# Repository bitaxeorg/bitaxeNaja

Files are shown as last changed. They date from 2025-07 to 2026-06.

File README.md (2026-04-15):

BitaxeNaja is a dual BM1340 Open Source Bitcoin miner using [esp-miner](https://github.com/skot/esp-miner)

The BM1340 used in this design is suspected to be a prototype version of the ASIC used in the Antminer S23 series miners.

It is still an untested prototype! Don't build this expecting it to work at all.
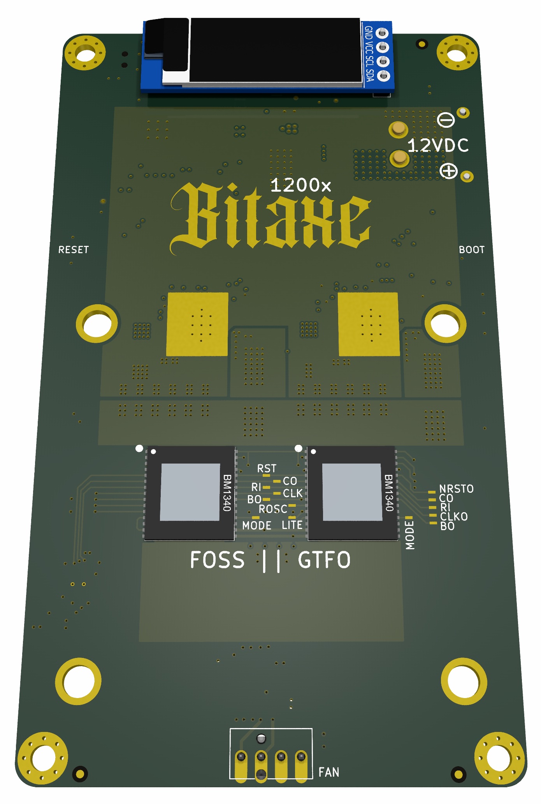
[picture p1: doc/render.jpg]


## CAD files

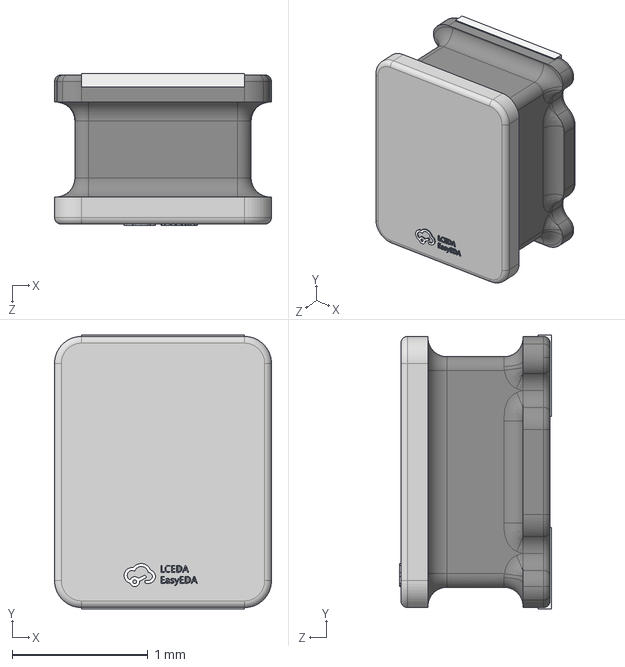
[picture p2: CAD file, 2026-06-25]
3d/IND-SMD_L2.0-W1.6-H1.1.step
1.60 x 2.02 x 1.12 mm

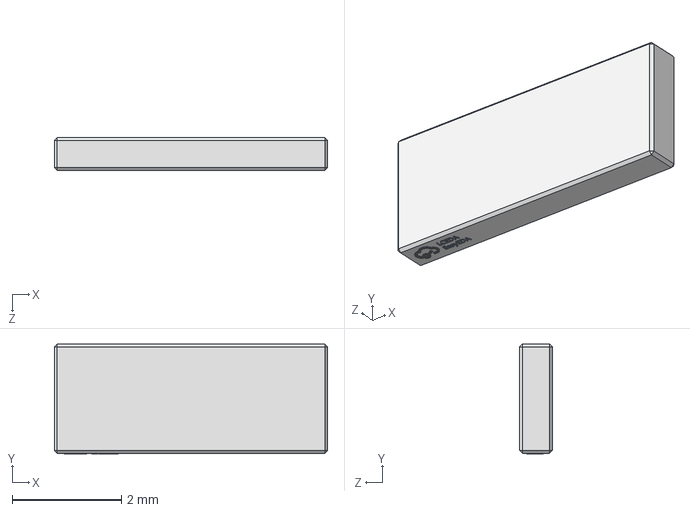
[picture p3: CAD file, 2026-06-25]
3d/PAD-SMD_L5.0-W2.0_STHW4-DU-HN050206.step
5.00 x 2.01 x 0.6 mm

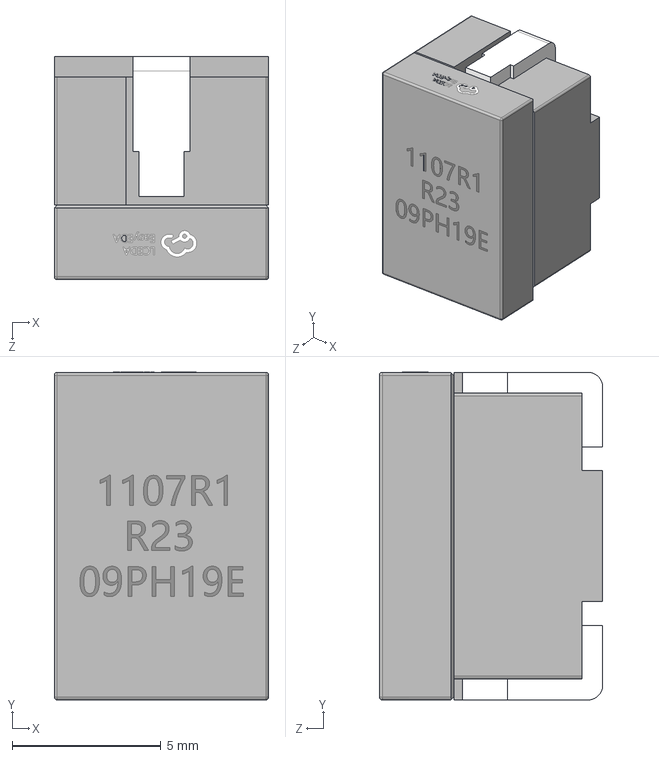
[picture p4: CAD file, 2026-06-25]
3d/IND-SMD_L11.0-W7.2-H7.5.step
7.20 x 11.0 x 7.50 mm

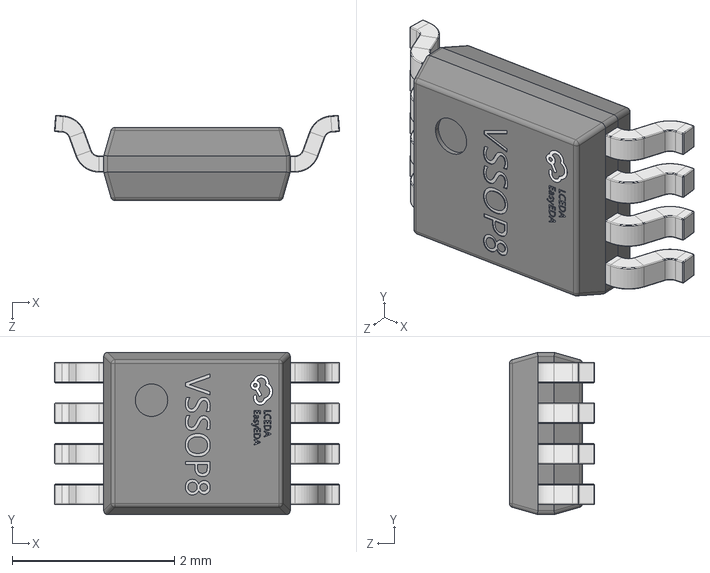
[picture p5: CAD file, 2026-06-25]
3d/VSSOP-8_L2.0-W2.3-H0.9-LS3.1-P0.50.step
3.51 x 2.00 x 1.05 mm

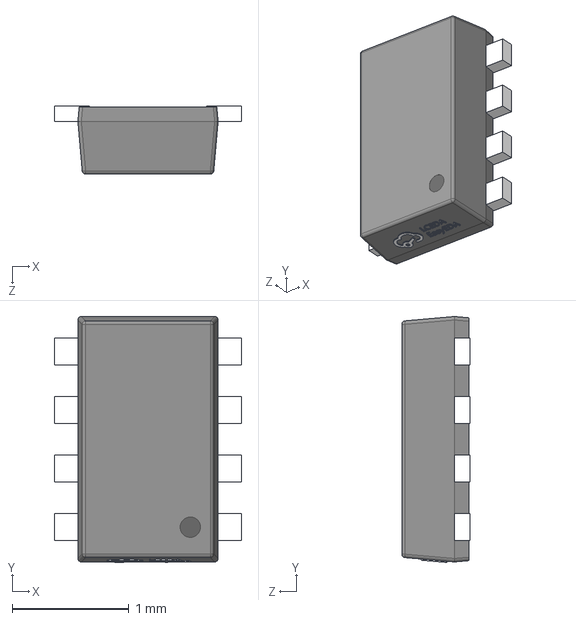
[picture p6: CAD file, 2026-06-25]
3d/SOT-583-8_L2.1-W1.2-P0.50-LS1.6-BR.step
1.60 x 2.10 x 0.585 mm

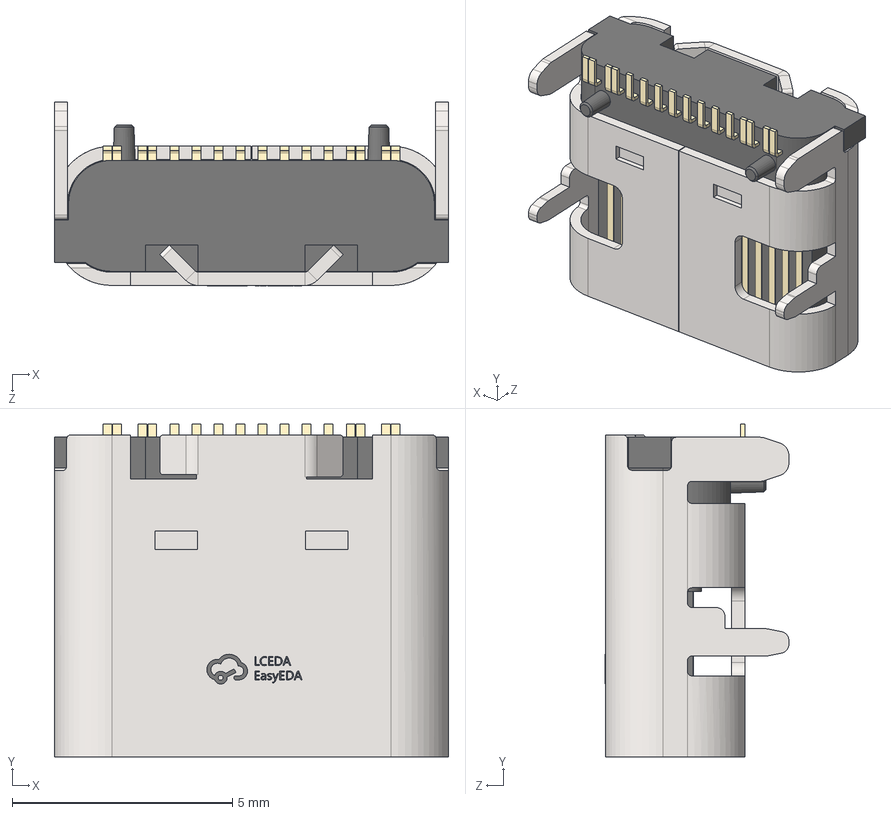
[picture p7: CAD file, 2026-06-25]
3d/TYPE-C-SMD_SBC-160S1A-20-S412.step
8.94 x 7.55 x 4.17 mm

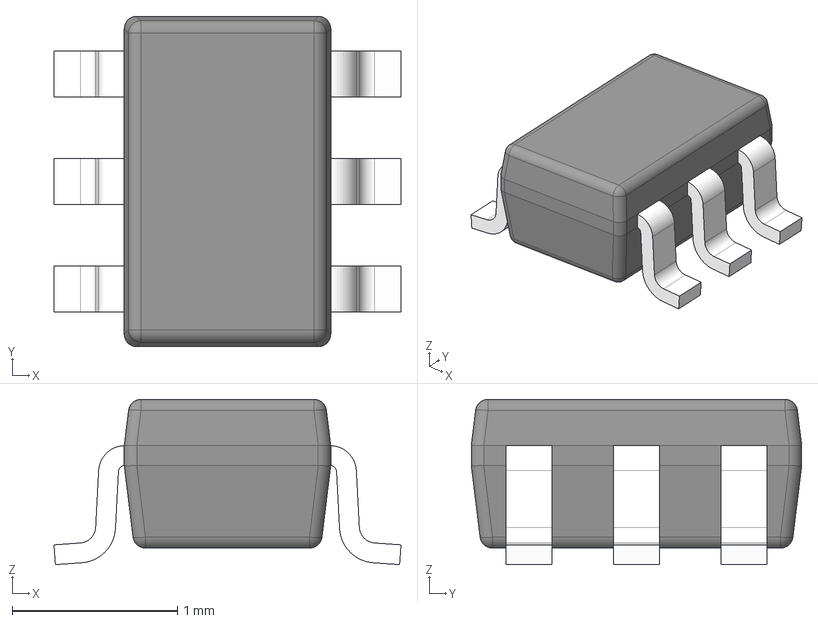
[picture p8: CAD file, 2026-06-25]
3d/DCK0006A.stp
2.10 x 2.00 x 1.00 mm
BODY-SOT
LEAD-SOT x 6
PIN1-ID

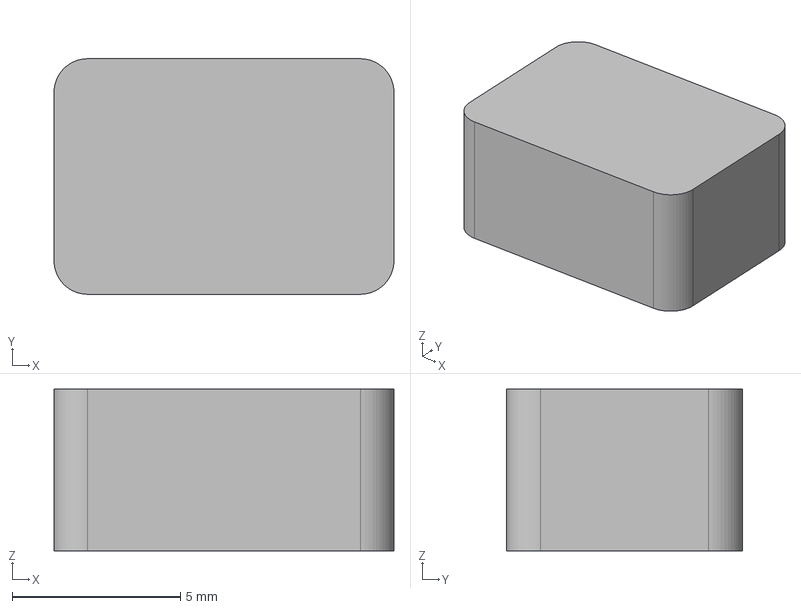
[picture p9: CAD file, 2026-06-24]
3d/GDIM107050-R15S1MTF-0R37.step
10.1 x 7.00 x 4.80 mm

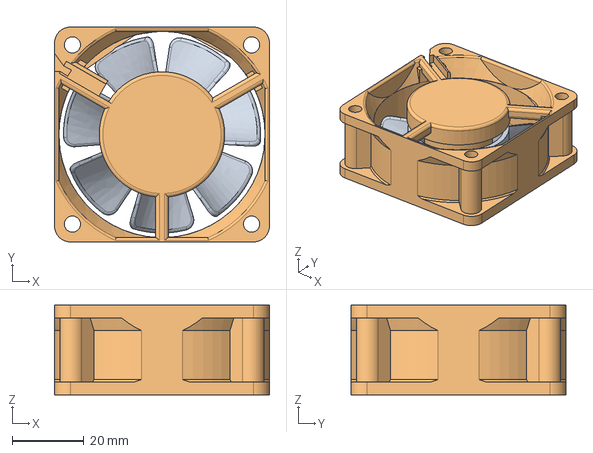
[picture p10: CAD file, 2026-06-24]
3d/Fan 60x60x25mm.stp
60.0 x 60.0 x 25.0 mm

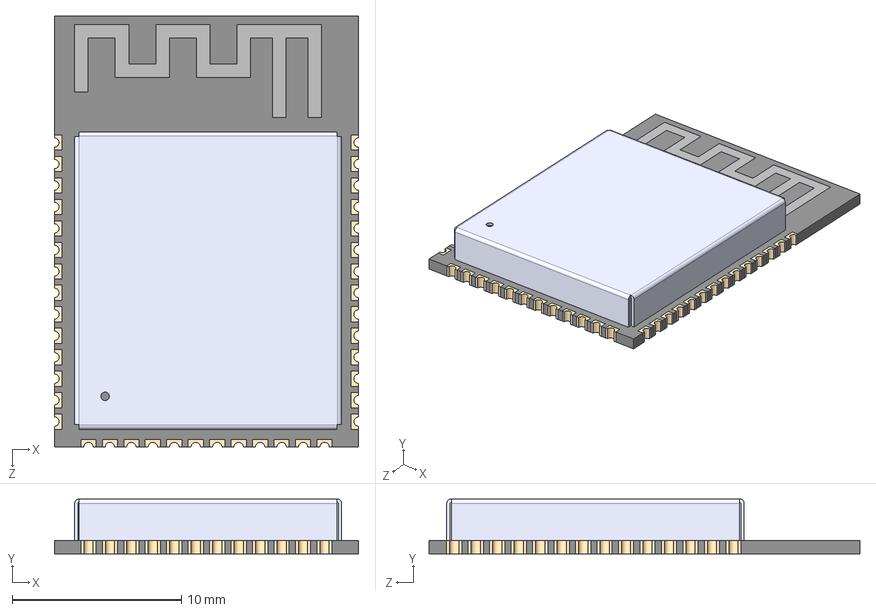
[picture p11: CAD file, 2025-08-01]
3d/ESP32-S3-WROOM-1-N8R2--3DModel-STEP-56544.STEP
18.0 x 3.25 x 25.5 mm

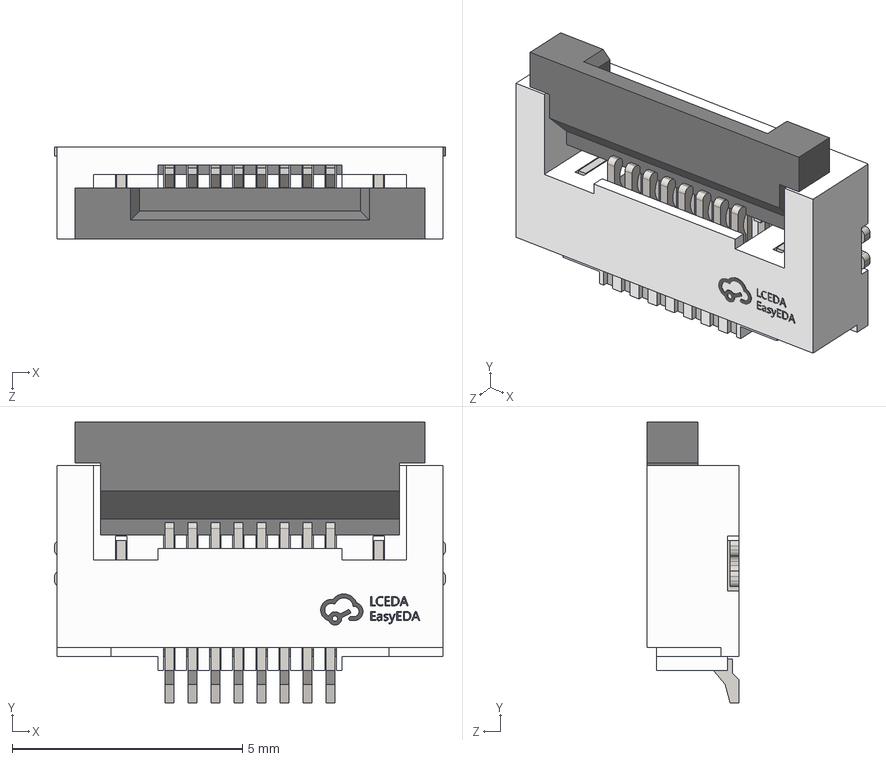
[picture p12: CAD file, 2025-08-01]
3d/FPC-SMD_P0.50-8P_FGS-XJ-H2.0.step
8.50 x 6.10 x 2.01 mm

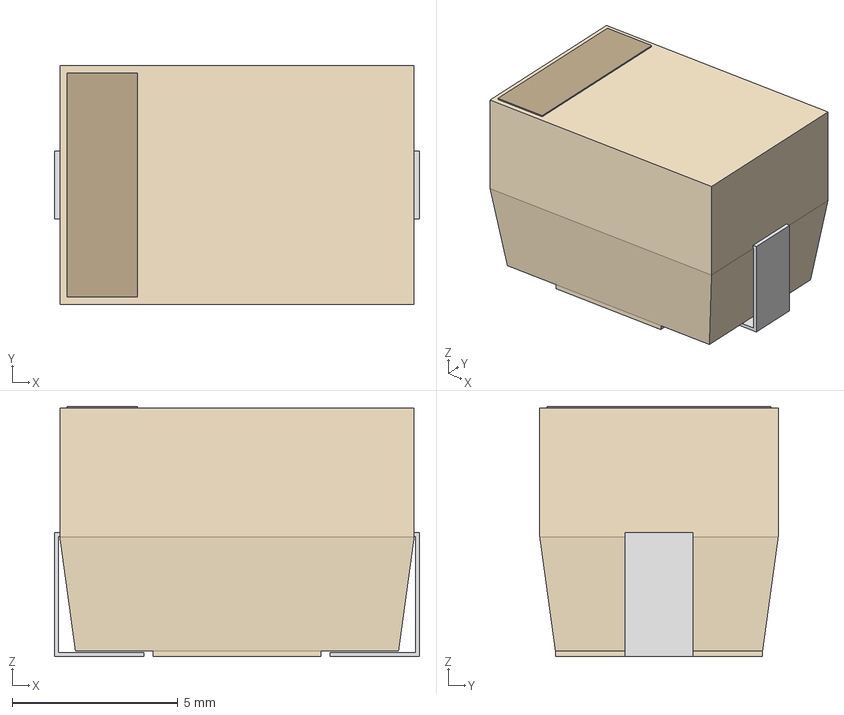
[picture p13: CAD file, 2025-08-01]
3d/IND_FP1107R1_EAT.step
11.0 x 7.19 x 7.54 mm

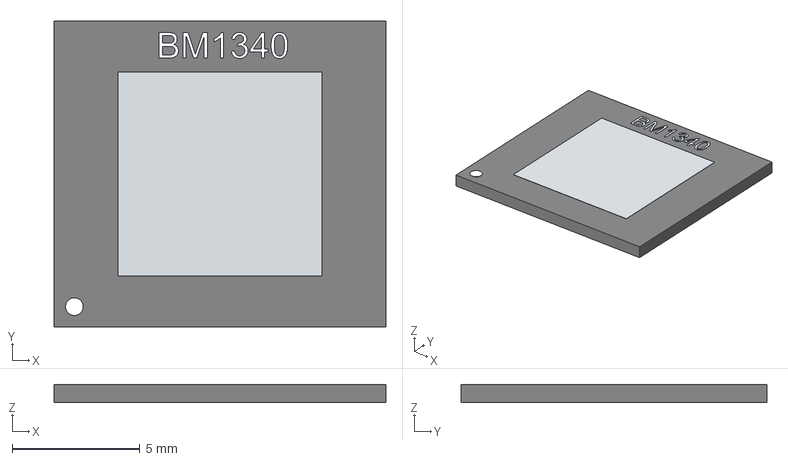
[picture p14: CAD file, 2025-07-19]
3d/BM1340.step
13.0 x 12.0 x 0.71 mm
Sketch002
Sketch003

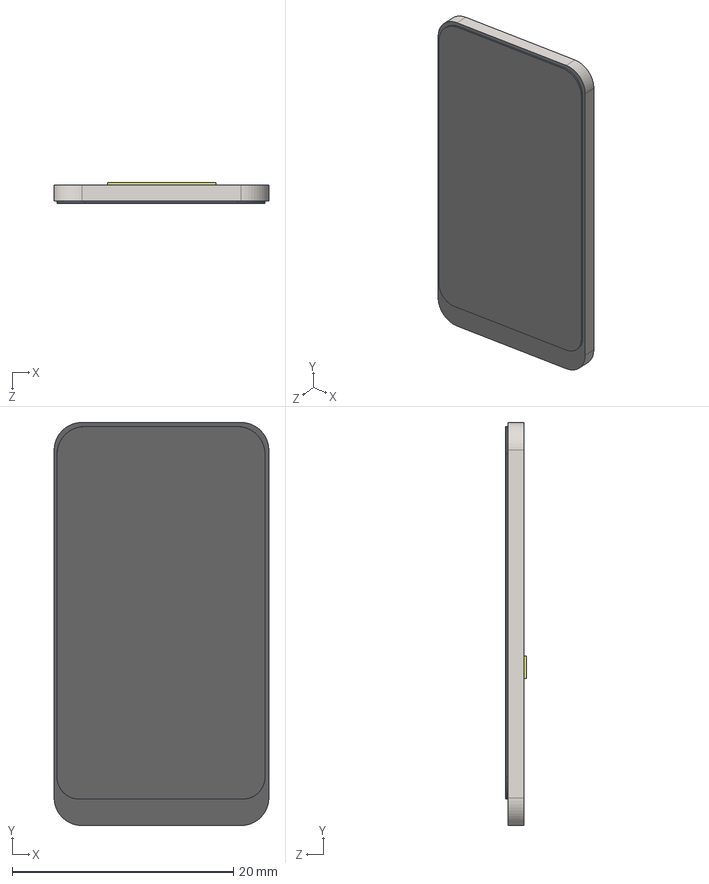
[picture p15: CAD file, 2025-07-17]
3d/DISST7789-176x320.STEP
19.4 x 36.4 x 1.86 mm

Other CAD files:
3d/TXB0104RGYR.STEP
3d/TPS546D24ARVFR.step
3d/BitaxeGT_heatsink.step
3d/BM04B-SRSS-TB.STEP
3d/141_TL3330AFxxxQG.stp
3d/21-0164B_L622-1_MXM.step
3d/2R5TPE220MAFB.step
3d/470531000.stp
3d/54-00164.STEP
3d/BM1368xx.stp
3d/BQB0016A.stp
3d/Bitaxe_Heatsink.step
3d/CS1213AG-tr.stp
3d/CUI_DEVICES_PJ-002AH.step
3d/CUI_DEVICES_PJ-036AH-SMT-TR.step
3d/CUI_DEVICES_PJ-037AH.step
3d/CX3225SB16000H0FLJCC.STEP
3d/Coilcraft-SLC1175.STEP
3d/Cree_PLCC6.stp
3d/DHVQFN14_SOT762-1_NEX.step
3d/DQG0008A.stp
3d/DQH0008A.stp
3d/DRC0010J.stp
3d/DRL0006A.stp
3d/FFC2B35-08-T.STEP
3d/FP1006V2-R.STEP
3d/FTSH-105-01-F-DV-K.stp
3d/GT heatsink.step
3d/IHLP2020CZ.step
3d/IND_-1R5MC_SUM.step
3d/OLED_0.91_128x32.stp
3d/PLCC6_LED_3_5X3_4X2_8_CRW.step
3d/QFN16_4X4_MCH.step
3d/SLC1175-271MEC_COC.step
3d/SMV_z90.stp
3d/SN74AXC1T45DBVR.STEP
3d/SOT-23-5_M5_MCH.step
3d/ST-4ETB2k_(202).stp
3d/SW_CS1213AGF260_CRS.step
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

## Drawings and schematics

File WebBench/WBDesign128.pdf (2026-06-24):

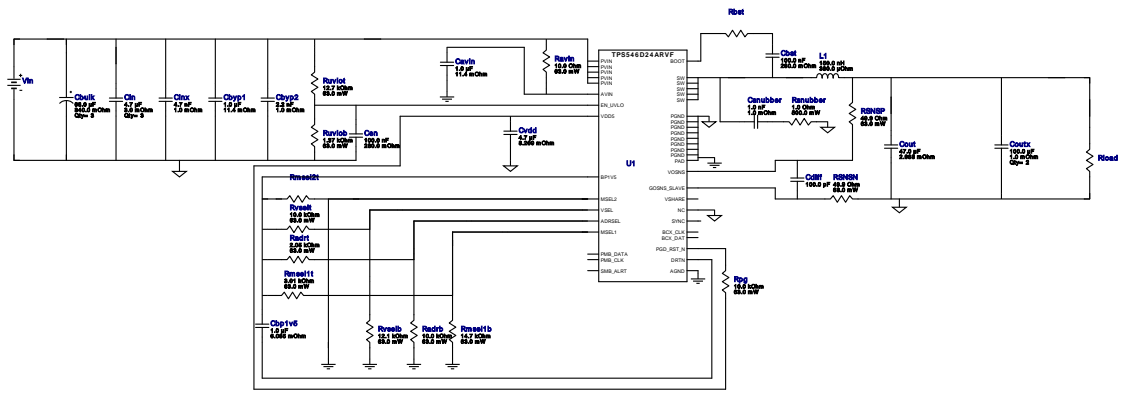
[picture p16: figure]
Cbyp2 2.2 nF 1.0 m Ohm; Cen 100.0 nF 280.0 m Ohm; Rsnubber 1.0 Ohm; Ruvlob 1.37 kOhm 63.0 m W; Cdiff 100.0 pF; Cavin 1.0 µF 11.4 m Ohm Ruvlot 12.7 kOhm; Coutx 100.0 µF 1.0 m Ohm Qty= 2; Cin 4.7 µF 3.0 m Ohm Qty= 3; RSNSN 49.9 Ohm 63.0 m W; Cout 47.0 µF; 2.988 m Ohm; RSNSP 49.9 Ohm 63.0 m W; Cinx 4.7 nF 1.0 m Ohm; Cbp1v5 1.0 µF 6.065 m Ohm; Cbyp1 1.0 µF 11.4 m Ohm; Rvselb 12.1 kOhm 63.0 m W; Rbst; Rpg 10.0 kOhm 63.0 m W; Ravin 10.0 Ohm 63.0 m W; Radrt 2.05 kOhm; Rm sel2t; Rvselt 10.0 kOhm; L1 150.0 nH 390.0 µOhm; Csnubber 1.0 nF; 1.0 m Ohm; Cbulk 68.0 µF 340.0 m Ohm; Qty= 3; Cvdd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

Copyright © 2026, Texas Instruments Incorporated | 1 | ti.com/webench

WEBENCH®
Design Report TPS546D24ARVFR : TPS546D24ARVFR 11V-13V to 2.20V @ 30A June 18, 2026 14:52:07 GMT-05:00

## WEBENCH ® Design Report

Design : 128 TPS546D24ARVFR
TPS546D24ARVFR 11V-13V to 2.20V @ 30A

VinMin = 11.0V
VinMax = 13.0V
Vout = 2.2V
Vout Sch = 2.2V
Iout = 30.0A

Device = TPS546D24ARVFR
Topology = Buck
Created = 2025-09-15 13:40:46.376 BOM Cost = $7.43
BOM Count = 34
Total Pd = 6.61W
1. Do not place Rmsel2t resistors. Place 0 Ohm resistor for Rbst.

### Design Alerts

Component Selection Information
The TPS546D24A is a PMBus(TM) device with key features listed below: PMBus(TM) features marked with * are included in WEBENCH(R) Power Designer. - Adaptive Voltage Scaling (AVS) through VOUT_COMMAND*, - Output voltage and current monitoring, - Thermal Shutdown,
- Programmable over current protection, - OCP,OV, UV, OT Levels, - Selectable Internal Compensation*, - Selectable Switching Frequency*,
- Turn-On and Turn-Off Delays, - UVLO*, Soft-Start*,OCP* and Soft-Stop. Use the Advanced Options on the left side to set the PMBus(TM) commands. Please refer to the TPS546D24A datasheet and visit http://www.ti.com/pmbus for more information.

## Electrical BOM

Name | Manufacturer | Part Number | Properties | Qty Price | Footprint
Cavin | TDK | C1005X5R1E105K050BC (https://product.tdk.com/ja/search/capacitor/ceramic/mlcc/info?part%5Fno%3DC1005X5R1E105K050BC) Series= X5R | Cap= 1.0 uF ESR= 11.4 mOhm VDC= 25.0 V IRMS= 0.0 A
1 | $0.02
| | | | | 0402 3 mm²
Cbp1v5 | MuRata | GRM188R60J105KA01D (http://psearch.en.murata.com/capacitor/result/smd/?status%3Dall%26pid%3DGRM188R60J105KA01D) Series= X5R

Cap= 1.0 uF
ESR= 6.065 mOhm
VDC= 6.3 V
IRMS= 1.36934 A

1 $0.01
0603 5 mm²
Cbst | AVX | 08053C104KAT2A (http://datasheets.avx.com/X7RDielectric.pdf) Series= X7R

Cap= 100.0 nF
ESR= 280.0 mOhm
VDC= 25.0 V
IRMS= 0.0 A

1 $0.01
0805 7 mm²

Design

Copyright © 2026, Texas Instruments Incorporated | 2 | ti.com/webench
Name | Manufacturer | Part Number | Properties | Qty Price | Footprint
Cbulk | Nichicon | UUD1V680MCL1GS (http://products.nichicon.co.jp/en/pdf/XJA043/e%2Dud.pdf) Series= uD | Cap= 68.0 uF ESR= 340.0 mOhm VDC= 35.0 V IRMS= 280.0 mA
3 | $0.10
| | | | | SM_RADIAL_6.3BMM 80 mm²
Cbyp1 | TDK | C1005X5R1E105K050BC (https://product.tdk.com/ja/search/capacitor/ceramic/mlcc/info?part%5Fno%3DC1005X5R1E105K050BC) Series= X5R | Cap= 1.0 uF ESR= 11.4 mOhm VDC= 25.0 V IRMS= 0.0 A
1 | $0.02
| | | | | 0402 3 mm²
Cbyp2 | MuRata | GRM155R61E222KA01D (http://search.murata.co.jp/Ceramy/PnsearchViewAction.do) Series= X5R

Cap= 2.2 nF
ESR= 1.0 mOhm
VDC= 25.0 V
IRMS= 0.0 A

1 $0.01
0402 3 mm²
Cdiff | Yageo | CC0201JRNPO8BN101 (http://www.yageo.com/documents/recent/UPY%2DGP%5FNP0%5F16V%2Dto%2D50V%5F10.pdf) Series= C0G/NP0

Cap= 100.0 pF
VDC= 5.0 V
IRMS= 0.0 A

1 $0.01
0201 2 mm²
Cen | AVX | 08053C104KAT2A (http://datasheets.avx.com/X7RDielectric.pdf) Series= X7R

Cap= 100.0 nF
ESR= 280.0 mOhm
VDC= 25.0 V
IRMS= 0.0 A

1 $0.01
0805 7 mm²
Cin | MuRata | GRM31CR71H475KA12L (http://search.murata.co.jp/Ceramy/PnsearchViewAction.do) Series= X7R

Cap= 4.7 uF
ESR= 3.0 mOhm
VDC= 50.0 V
IRMS= 4.98 A

3 $0.10
1206 11 mm²
Cinx | MuRata | GRM155R71E472KA01D (http://search.murata.co.jp/Ceramy/PnsearchViewAction.do) Series= X7R

Cap= 4.7 nF
ESR= 1.0 mOhm
VDC= 25.0 V
IRMS= 0.0 A

1 $0.01
0402 3 mm²
Cout | Taiyo Yuden | MSASJ21GBB5476MTNA01 (https://ds.yuden.co.jp/TYCOMPAS/ut/detail?pn%3DMSASJ21GBB5476MTNA01%26u%3DM) Series= X5R

Cap= 47.0 uF
ESR= 2.988 mOhm
VDC= 6.3 V
IRMS= 3.5841 A

1 $0.09
0805 7 mm²
Coutx | MuRata | GRM32EC80J107ME20L Series= X6S

Cap= 100.0 uF
ESR= 1.0 mOhm
VDC= 6.3 V
IRMS= 6.0 A

2 $0.17
1210_270 15 mm²
Csnubber Yageo | CC0805KRX7R9BB102 (http://www.yageo.com/documents/recent/UPY%2DGPHC%5FX7R%5F6.3V%2Dto%2D50V%5F7.pdf)
| | Series= X7R
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

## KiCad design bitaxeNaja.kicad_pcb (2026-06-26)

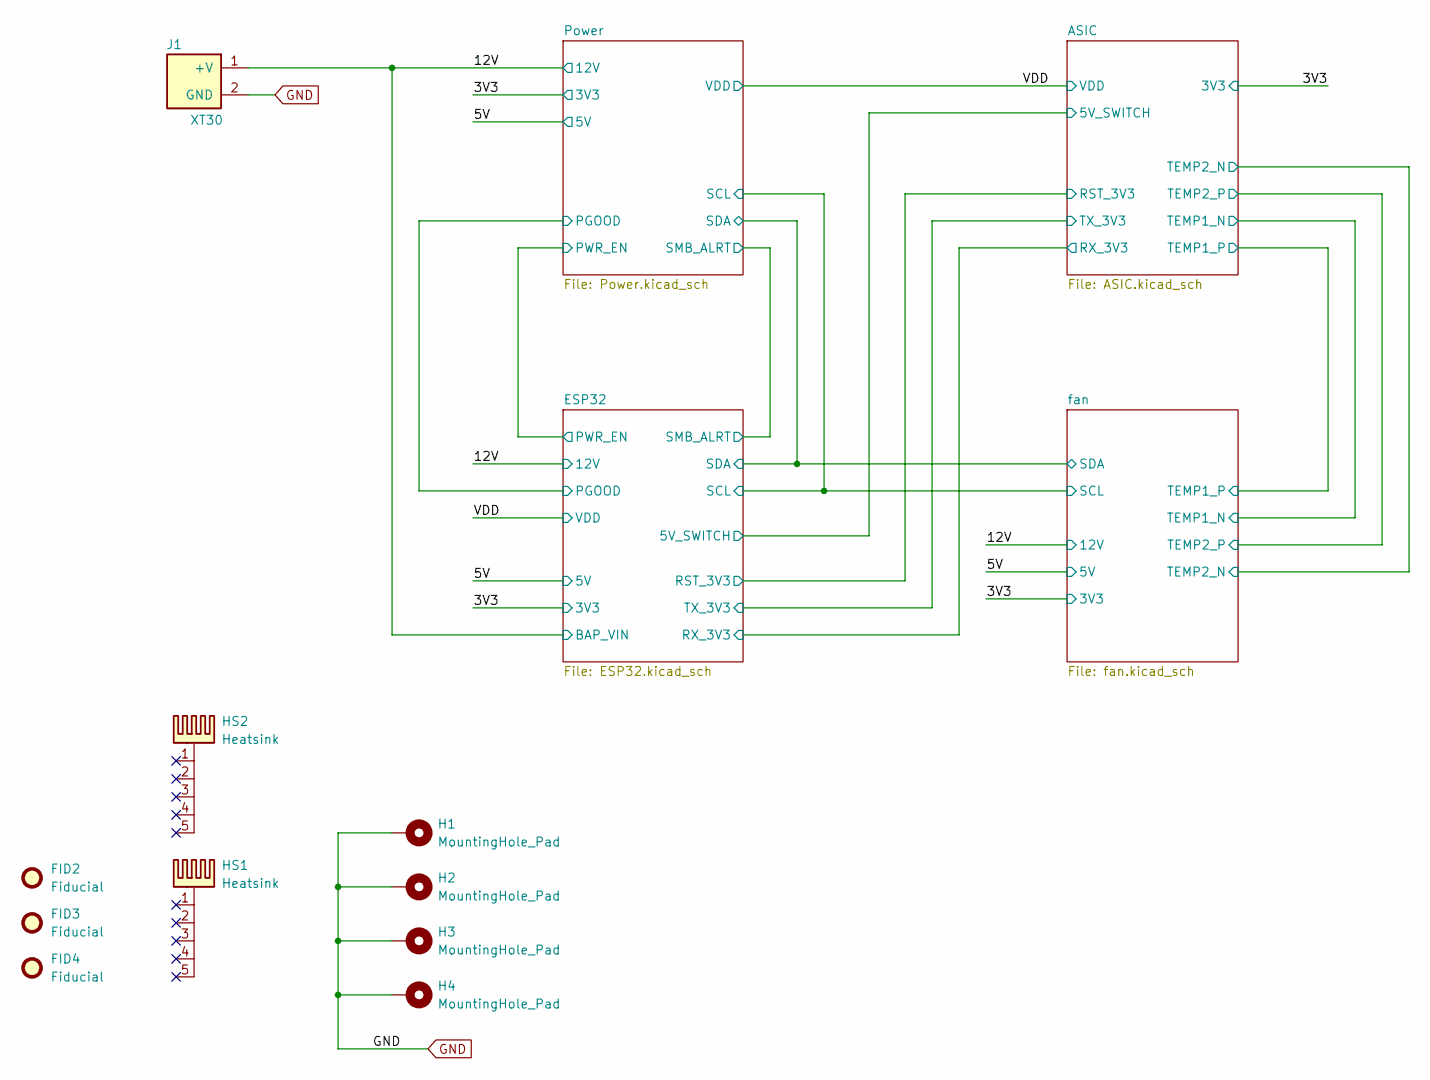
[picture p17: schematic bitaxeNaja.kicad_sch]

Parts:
FID2, FID3, FID4: Fiducial; Fiducial_1mm_Mask2mm
H1, H2, H3, H4: MountingHole_Pad; MountingHole_3.2mm_M3_Pad_Via
HS1: Heatsink; Heatsink-5hole-BitaxeGT
HS2: Heatsink; 70mm-mounting_HTPC
J1: XT30; XT30PW-M; PARTNO XT30PW-M; LCSC C431092

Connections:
/12V: J1.1 (+V); also elsewhere on the board
GND: H1.1 (1_1), H2.1 (1_1), H3.1 (1_1), H4.1 (1_1), J1.2 (GND); also elsewhere on the board

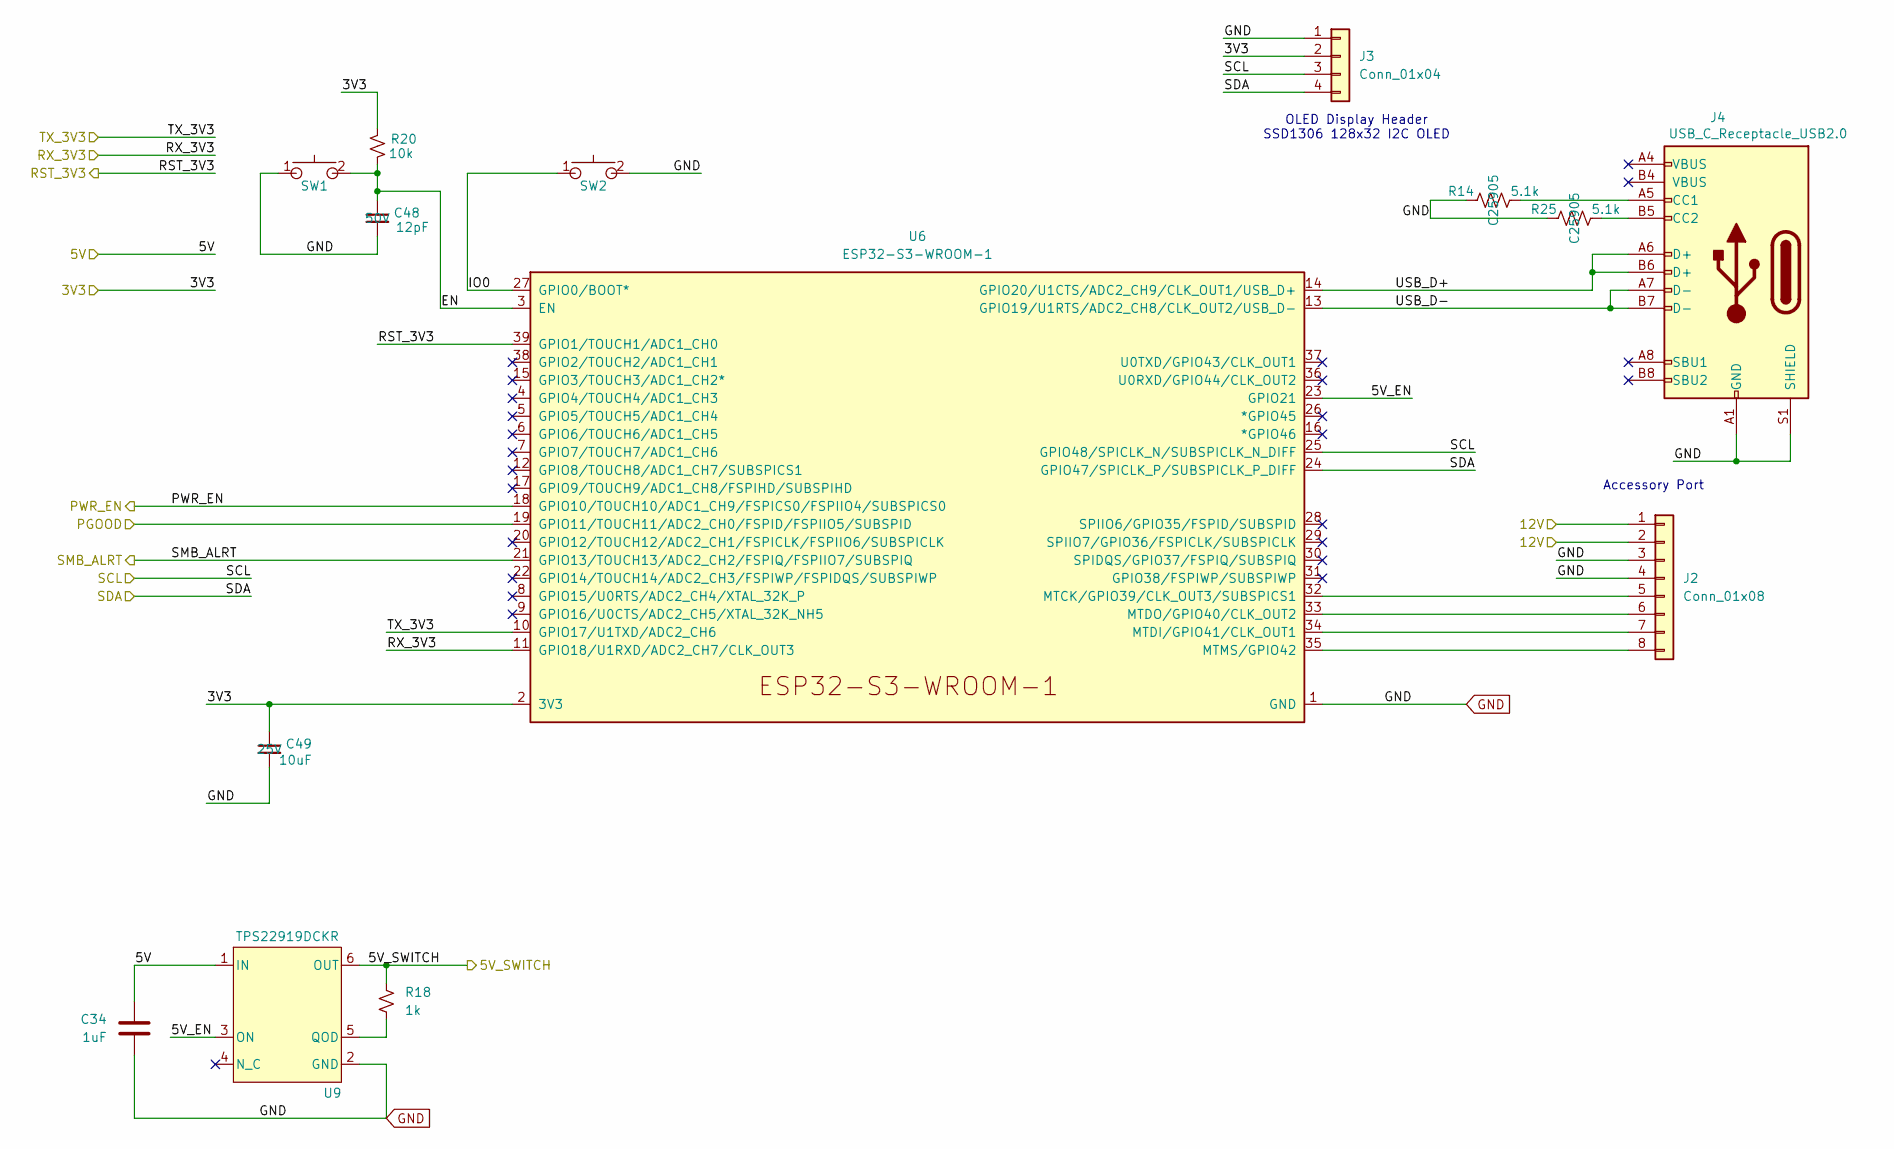
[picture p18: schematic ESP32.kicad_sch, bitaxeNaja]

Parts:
C34: 1uF; C_0402_1005Metric; PARTNO EMK105BJ105MV-F; LCSC C52923
C48: 12pF; C_0402_1005Metric; Voltage 50V; PARTNO CC0402JRNPO9BN120
C49: 10uF; C_0603_1608Metric; Voltage 25V; PARTNO GRM188R61E106KA73D
J2: Conn_01x08; FPC-SMD_P0.50-8P_FGS-XJ-H2.0; PARTNO FFC2B35-08-T; LCSC C262657
J3: Conn_01x04; PinHeader_1x04_P2.54mm_Vertical_shifted
J4: USB_C_Receptacle_USB2.0; USB_C_Receptacle_GCT_USB4105-xx-A; PARTNO USB4105-GF-A
R14, R25: 5.1k; R_0402_1005Metric; PARTNO RMCF0402JT5K10; LCSC C25905
R18: 1k; R_0402_1005Metric; PARTNO RC0402FR-071KL
R20: 10k; R_0402_1005Metric; PARTNO RC0402JR-0710KL
SW1, SW2: SWITCH-SPST; SW_TL3330AF130QG_EWI; PARTNO TL3330AF130QG
U6: ESP32-S3-WROOM-1; PARTNO ESP32-S3-WROOM-1-N16R8
U9: TPS22919DCKR; DCK0006A_N; PARTNO TPS22919DCKR

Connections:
/3V3: C49.1, J3.2, R20.2, U6.2 (3V3); also elsewhere on the board
/5V: C34.1, U9.1 (IN); also elsewhere on the board
/12V: J2.1, J2.2; also elsewhere on the board
/ASIC/5V_SWITCH: R18.1, U9.6 (OUT); also elsewhere on the board
/ASIC/RST_3V3: U6.39 (GPIO1/TOUCH1/ADC1_CH0); also elsewhere on the board
/ASIC/RX_3V3: U6.11 (GPIO18/U1RXD/ADC2_CH7/CLK_OUT3); also elsewhere on the board
/ASIC/TX_3V3: U6.10 (GPIO17/U1TXD/ADC2_CH6); also elsewhere on the board
/ESP32/5V_EN: U6.23 (GPIO21), U9.3 (ON)
/ESP32/EN: C48.1, R20.1, SW1.2, U6.3 (EN)
/ESP32/IO0: SW2.1, U6.27 (GPIO0/BOOT*)
/ESP32/PWR_EN: U6.18 (GPIO10/TOUCH10/ADC1_CH9/FSPICS0/FSPIIO4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); also elsewhere on the board
/ESP32/SCL: J3.3, U6.25 (GPIO48/SPICLK_N/SUBSPICLK_N_DIFF); also elsewhere on the board
/ESP32/SDA: J3.4, U6.24 (GPIO47/SPICLK_P/SUBSPICLK_P_DIFF); also elsewhere on the board
/ESP32/SMB_ALRT: U6.21 (GPIO13/TOUCH13/ADC2_CH2/FSPIQ/FSPIIO7/S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); also elsewhere on the board
/ESP32/USB_D+: J4.A6 (D+), J4.B6 (D+), U6.14 (GPIO20/U1CTS/ADC2_CH9/CLK_OUT1/USB_D+)
/ESP32/USB_D-: J4.A7 (D-), J4.B7 (D-), U6.13 (GPIO19/U1RTS/ADC2_CH8/CLK_OUT2/USB_D-)
/Power/PGOOD: U6.19 (GPIO11/TOUCH11/ADC2_CH0/FSPID/FSPIIO5/S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); also elsewhere on the board
GND: C34.2, C48.2, C49.2, J2.3, J2.4, J3.1, J4.A1 (GND), J4.B1 (GND), J4.S1 (SHIELD), R14.1, R25.1, SW1.1, SW2.2, U6.1 (GND), U6.40 (GND), U6.41 (GND), U9.2 (GND); also elsewhere on the board
unnamed: J2.5, U6.32 (MTCK/GPIO39/CLK_OUT3/SUBSPICS1)
unnamed: J2.6, U6.33 (MTDO/GPIO40/CLK_OUT2)
unnamed: J2.7, U6.34 (MTDI/GPIO41/CLK_OUT1)
unnamed: J2.8, U6.35 (MTMS/GPIO42)
unnamed: J4.A5 (CC1), R14.2
unnamed: J4.B5 (CC2), R25.2
unnamed: R18.2, U9.5 (QOD)

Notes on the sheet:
OLED Display Header SSD1306 128x32 I2C OLED
Accessory Port

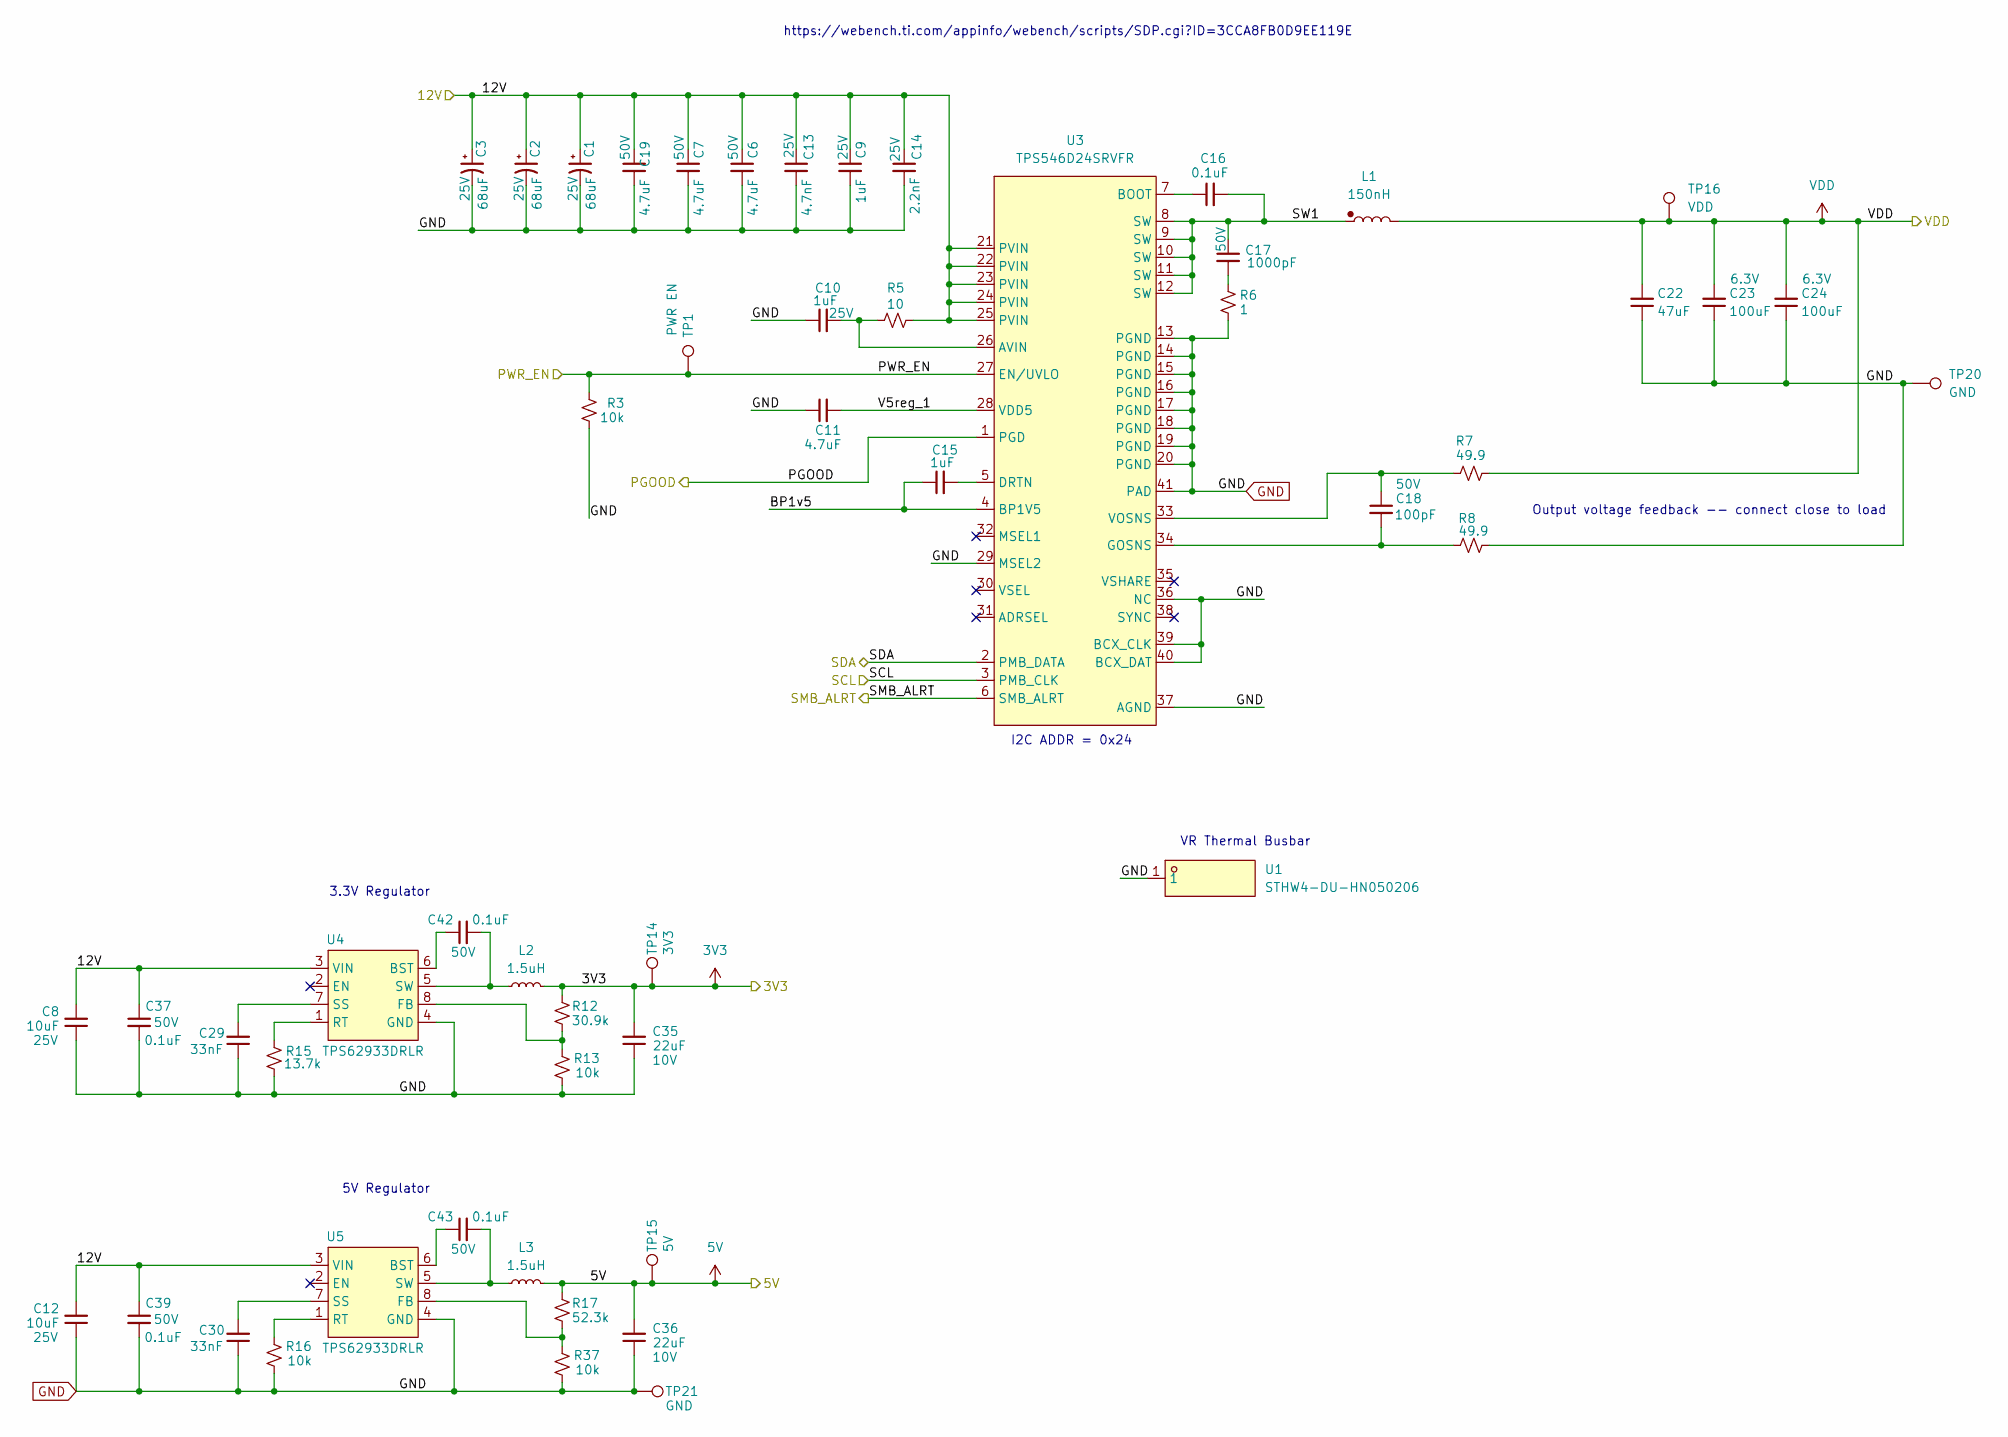
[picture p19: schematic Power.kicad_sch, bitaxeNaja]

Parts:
C1, C2, C3: 68uF; CP_Elec_5x5.8; Voltage 25V; PARTNO UCM1E680MCL1GS
C6, C7, C19: 4.7uF; C_1206_3216Metric; Voltage 50V; PARTNO GRM31CR71H475KA12L
C8, C12: 10uF; C_0603_1608Metric; Voltage 25V; PARTNO GRM188R61E106KA73D; LCSC C15850
C9, C10: 1uF; C_0603_1608Metric; Voltage 25V; PARTNO CL10B105KA8NNNC
C11: 4.7uF; C_0402_1005Metric; PARTNO GRM155R61A475MEAAD
C13: 4.7nF; C_0402_1005Metric; Voltage 25V; PARTNO GRM155R71E472KA01D
C14: 2.2nF; C_0402_1005Metric; Voltage 25V; PARTNO GRM155R61H222KA01D
C15: 1uF; C_0402_1005Metric; PARTNO EMK105BJ105MV-F; LCSC C52923
C16, C37, C39, C42, C43: 0.1uF; C_0402_1005Metric; Voltage 50V; PARTNO GRM155R71H104KE14D; LCSC C77020
C17: 1000pF; C_0805_2012Metric; Voltage 50V; PARTNO CC0805KRX7R9BB102
C18: 100pF; C_0402_1005Metric; Voltage 50V; PARTNO CC0402JRNPO9BN101
C22: 47uF; C_0805_2012Metric; PARTNO MSASJ21GBB5476MTNA01; LCSC C45783
C23, C24: 100uF; C_1210_3225Metric; Voltage 6.3V; PARTNO GRM32EC80J107ME20L
C29, C30: 33nF; C_0402_1005Metric; PARTNO CC0402KRX7R9BB333; LCSC C106862
C35, C36: 22uF; C_0805_2012Metric; Voltage 10V; PARTNO CL21A226MPQNNNE; LCSC C45783
L1: 150nH; GDIM107050-R15S1MTF-0R37; LCSC C49237960
L2, L3: 1.5uH; IND-SMD_L2.0-W1.6; PARTNO FTC201612S1R5MBCA; LCSC C5832350
R3, R13, R16, R37: 10k; R_0402_1005Metric; PARTNO RC0402JR-0710KL; LCSC C25744
R5: 10; R_0402_1005Metric; PARTNO RC0402FR-0710RL
R6: 1; R_0805_2012Metric; PARTNO ESR10EZPJ1R0
R7, R8: 49.9; R_0402_1005Metric; PARTNO RC0402FR-0749R9L
R12: 30.9k; R_0402_1005Metric; PARTNO RC0402FR-0730K9L; LCSC C185428
R15: 13.7k; R_0402_1005Metric; PARTNO RC0402FR-0713K7L; LCSC C274888
R17: 52.3k; R_0402_1005Metric; PARTNO RC0402FR-0752K3L
TP1: PWR EN; TestPoint_Pad_D1.0mm
TP14: 3V3; TestPoint_Pad_D1.0mm
TP15: 5V; TestPoint_Pad_D1.0mm
TP16: VDD; TestPoint_Pad_D1.0mm
TP20: GND; TestPoint_Pad_D1.0mm
TP21: GND; TestPoint_Pad_D1.0mm; LCSC C138021
U1: STHW4-DU-HN050206; PAD-SMD_L5.0-W2.0_STHW4-DU-HN050206; LCSC C18548300
U3: TPS546D24SRVFR; LQFN40-CLIP; PARTNO TPS546D24SRVFR
U4, U5: TPS62933DRLR; SOT-583-8_L2.1-W1.2-P0.50-LS1.6-BR; PARTNO TPS62933DRLR; LCSC C3200405

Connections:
/3V3: C35.2, L2.2, R12.2, TP14.1 (1_1); also elsewhere on the board
/5V: C36.2, L3.2, R17.2, TP15.1 (1_1); also elsewhere on the board
/12V: C1.1, C2.1, C3.1, C6.1, C7.1, C8.2, C9.1, C12.2, C13.1, C14.1, C19.1, C37.1, C39.1, R5.1, U3.21 (PVIN), U3.22 (PVIN), U3.23 (PVIN), U3.24 (PVIN), U3.25 (PVIN), U4.3 (VIN), U5.3 (VIN); also elsewhere on the board
/ESP32/PWR_EN: R3.2, TP1.1 (1_1), U3.27 (EN/UVLO); also elsewhere on the board
/ESP32/SCL: U3.3 (PMB_CLK); also elsewhere on the board
/ESP32/SDA: U3.2 (PMB_DATA); also elsewhere on the board
/ESP32/SMB_ALRT: U3.6 (SMB_ALRT); also elsewhere on the board
/Power/BP1v5: C15.1, U3.4 (BP1V5)
/Power/PGOOD: U3.1 (PGD); also elsewhere on the board
/Power/SW1: C16.2, C17.1, L1.1, U3.8 (SW), U3.9 (SW), U3.10 (SW), U3.11 (SW), U3.12 (SW)
/Power/V5reg_1: C11.2, U3.28 (VDD5)
/VDD: C22.2, C23.2, C24.2, L1.2, R7.1, TP16.1 (1_1); also elsewhere on the board
GND: C1.2, C2.2, C3.2, C6.2, C7.2, C8.1, C9.2, C10.1, C11.1, C12.1, C13.2, C14.2, C19.2, C22.1, C23.1, C24.1, C29.1, C30.1, C35.1, C36.1, C37.2, C39.2, R3.1, R6.2, R8.2, R13.1, R15.1, R16.1, R37.1, TP20.1 (1_1), TP21.1 (1_1), U1.1 (1_1), U3.13 (PGND), U3.14 (PGND), U3.15 (PGND), U3.16 (PGND), U3.17 (PGND), U3.18 (PGND), U3.19 (PGND), U3.20 (PGND), U3.29 (MSEL2), U3.36 (NC), U3.37 (AGND), U3.39 (BCX_CLK), U3.40 (BCX_DAT), U3.41 (PAD), U4.4 (GND), U5.4 (GND); also elsewhere on the board
unnamed: C17.2, R6.1
unnamed: C10.2, R5.2, U3.26 (AVIN)
unnamed: C16.1, U3.7 (BOOT)
unnamed: C15.2, U3.5 (DRTN)
unnamed: C18.2, R8.1, U3.34 (GOSNS)
unnamed: C18.1, R7.2, U3.33 (VOSNS)
unnamed: C42.1, U4.6 (BST)
unnamed: R12.1, R13.2, U4.8 (FB)
unnamed: R15.2, U4.1 (RT)
unnamed: C29.2, U4.7 (SS)
unnamed: C42.2, L2.1, U4.5 (SW)
unnamed: C43.1, U5.6 (BST)
unnamed: R17.1, R37.2, U5.8 (FB)
unnamed: R16.2, U5.1 (RT)
unnamed: C30.2, U5.7 (SS)
unnamed: C43.2, L3.1, U5.5 (SW)

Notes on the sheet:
https://webench.ti.com/appinfo/webench/scripts/SDP.cgi?ID=3CCA8FB0D9EE119E
VR Thermal Busbar
I2C ADDR = 0x24
Output voltage feedback -- connect close to load
5V Regulator
3.3V Regulator

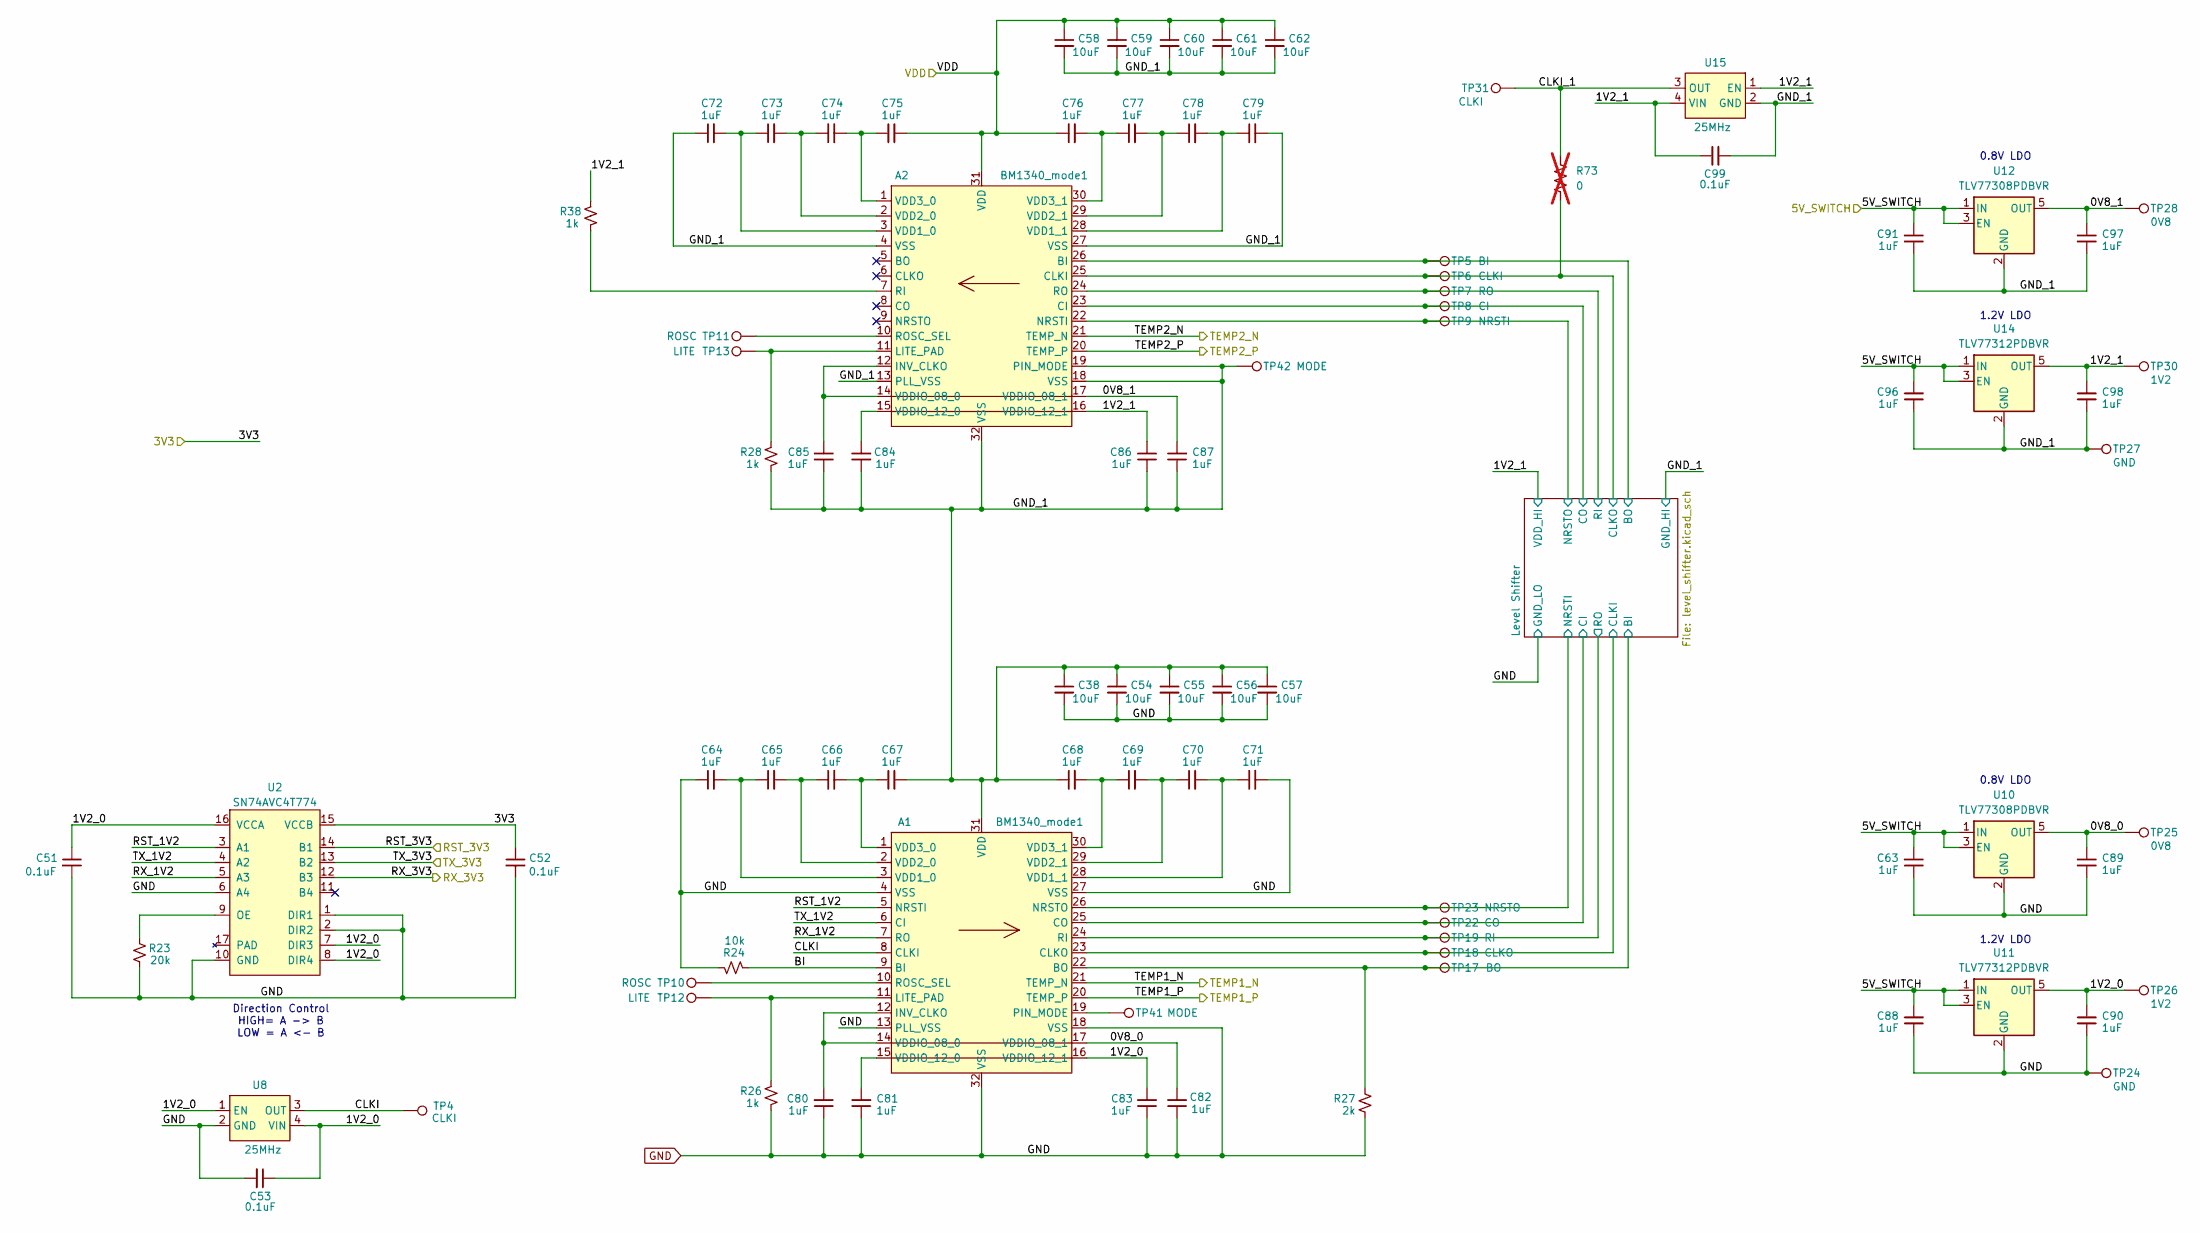
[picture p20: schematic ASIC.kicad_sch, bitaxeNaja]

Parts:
A1, A2: BM1340_mode1; BM1340
C38, C54, C55, C56, C57, C58, C59, C60, C61, C62: 10uF; C_0603_1608Metric; Voltage 25V; PARTNO GRM188R61E106KA73D
C51, C52, C53, C99: 0.1uF; C_0402_1005Metric; PARTNO KGM05AR71C104KH
C63, C88, C89, C90, C91, C96, C97, C98: 1uF; C_0402_1005Metric; PARTNO EMK105BJ105MV-F; LCSC C52923
C64, C65, C66, C67, C68, C69, C70, C71, C72, C73, C74, C75, C76, C77, C78, C79, C80, C81, C82, C83, C84, C85, C86, C87: 1uF; C_0402_1005Metric; PARTNO EMK105BJ105MV-F
R23: 20k; R_0402_1005Metric; PARTNO RC0402FR-0720KL
R24: 10k; R_0402_1005Metric; PARTNO RC0402JR-0710KL
R26, R28, R38: 1k; R_0402_1005Metric; PARTNO RC0402FR-071KL
R27: 2k; R_0402_1005Metric; PARTNO RT0402BRD072KL
R73: 0; R_0402_1005Metric; PARTNO RC0402JR-070RL; not fitted
TP4, TP31: CLKI; TestPoint_Pad_D1.0mm
TP5: BI; TestPoint_Pad_1.0x0.4mm
TP6: CLKI; TestPoint_Pad_1.0x0.4mm
TP7: RO; TestPoint_Pad_1.0x0.4mm
TP8: CI; TestPoint_Pad_1.0x0.4mm
TP9: NRSTI; TestPoint_Pad_1.0x0.4mm
TP10, TP11: ROSC; TestPoint_Pad_1.0x0.4mm
TP12, TP13: LITE; TestPoint_Pad_1.0x0.4mm
TP17: BO; TestPoint_Pad_1.0x0.4mm
TP18: CLKO; TestPoint_Pad_1.0x0.4mm
TP19: RI; TestPoint_Pad_1.0x0.4mm
TP22: CO; TestPoint_Pad_1.0x0.4mm
TP23: NRSTO; TestPoint_Pad_1.0x0.4mm
TP24, TP27: GND; TestPoint_Pad_D1.0mm
TP25, TP28: 0V8; TestPoint_Pad_D1.0mm
TP26, TP30: 1V2; TestPoint_Pad_D1.0mm
TP41, TP42: MODE; TestPoint_Pad_1.0x0.4mm
U2: SN74AVC4T774; BQB0016A-MFG; PARTNO SN74AXC4T774BQBR
U8, U15: 25MHz; SMD3225-4P; PARTNO SX3M25.000E20F30THN; LCSC C5137262
U10, U12: TLV77308PDBVR; SOT-23-5; PARTNO TLV77308PDBVR
U11, U14: TLV77312PDBVR; SOT-23-5; PARTNO TLV77312PDBVR

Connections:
/3V3: C52.1, U2.15 (VCCB); also elsewhere on the board
/ASIC/5V_SWITCH: C63.2, C88.2, C91.2, C96.2, U10.1 (IN), U10.3 (EN), U11.1 (IN), U11.3 (EN), U12.1 (IN), U12.3 (EN), U14.1 (IN), U14.3 (EN); also elsewhere on the board
/ASIC/BI: A1.9 (BI), R24.2
/ASIC/CLKI: A1.8 (CLKI), TP4.1 (1_1), U8.3 (OUT)
/ASIC/CLKI_1: R73.2, TP31.1 (1_1), U15.3 (OUT)
/ASIC/GND_1: A1.31 (VDD), A2.4 (VSS), A2.13 (PLL_VSS), A2.18 (VSS), A2.19 (PIN_MODE), A2.27 (VSS), A2.32 (VSS), C38.1, C54.1, C55.1, C56.1, C57.1, C58.2, C59.2, C60.2, C61.2, C62.2, C67.2, C68.1, C72.1, C79.2, C84.1, C85.1, C86.1, C87.1, C91.1, C96.1, C97.1, C98.1, C99.2, R28.1, TP27.1 (1_1), TP42.1 (1_1), U12.2 (GND), U14.2 (GND), U15.2 (GND); also elsewhere on the board
/ASIC/Level Shifter/BI: A1.22 (BO), R27.2, TP17.1 (1_1); also elsewhere on the board
/ASIC/Level Shifter/BI2: A2.26 (BI), TP5.1 (1_1); also elsewhere on the board
/ASIC/Level Shifter/CI: A1.25 (CO), TP22.1 (1_1); also elsewhere on the board
/ASIC/Level Shifter/CI2: A2.23 (CI), TP8.1 (1_1); also elsewhere on the board
/ASIC/Level Shifter/CLKI: A1.23 (CLKO), TP18.1 (1_1); also elsewhere on the board
/ASIC/Level Shifter/CLKO: A2.25 (CLKI), R73.1, TP6.1 (1_1); also elsewhere on the board
/ASIC/Level Shifter/NRSTI: A1.26 (NRSTO), TP23.1 (1_1); also elsewhere on the board
/ASIC/Level Shifter/NRSTI2: A2.22 (NRSTI), TP9.1 (1_1); also elsewhere on the board
/ASIC/Level Shifter/RO: A1.24 (RI), TP19.1 (1_1); also elsewhere on the board
/ASIC/Level Shifter/RO2: A2.24 (RO), TP7.1 (1_1); also elsewhere on the board
/ASIC/RST_1V2: A1.5 (NRSTI), U2.3 (A1)
/ASIC/RST_3V3: U2.14 (B1); also elsewhere on the board
/ASIC/RX_1V2: A1.7 (RO), U2.5 (A3)
/ASIC/RX_3V3: U2.12 (B3); also elsewhere on the board
/ASIC/TEMP1_N: A1.21 (TEMP_N); also elsewhere on the board
/ASIC/TEMP1_P: A1.20 (TEMP_P); also elsewhere on the board
/ASIC/TEMP2_N: A2.21 (TEMP_N); also elsewhere on the board
/ASIC/TEMP2_P: A2.20 (TEMP_P); also elsewhere on the board
/ASIC/TX_1V2: A1.6 (CI), U2.4 (A2)
/ASIC/TX_3V3: U2.13 (B2); also elsewhere on the board
/VDD: A2.31 (VDD), C58.1, C59.1, C60.1, C61.1, C62.1, C75.2, C76.1; also elsewhere on the board
GND: A1.4 (VSS), A1.13 (PLL_VSS), A1.18 (VSS), A1.27 (VSS), A1.32 (VSS), C38.2, C51.2, C52.2, C53.2, C54.2, C55.2, C56.2, C57.2, C63.1, C64.1, C71.2, C80.1, C81.1, C82.1, C83.1, C88.1, C89.1, C90.1, R23.1, R24.1, R26.1, R27.1, TP24.1 (1_1), U2.1 (DIR1), U2.2 (DIR2), U2.6 (A4), U2.10 (GND), U8.2 (GND), U10.2 (GND), U11.2 (GND); also elsewhere on the board
unnamed: A1.11 (LITE_PAD), R26.2, TP12.1 (1_1)
unnamed: A1.19 (PIN_MODE), TP41.1 (1_1)
unnamed: A1.10 (ROSC_SEL), TP10.1 (1_1)
unnamed: A1.3 (VDD1_0), C64.2, C65.1
unnamed: A1.28 (VDD1_1), C70.2, C71.1
unnamed: A1.2 (VDD2_0), C65.2, C66.1
unnamed: A1.29 (VDD2_1), C69.2, C70.1
unnamed: A1.1 (VDD3_0), C66.2, C67.1
unnamed: A1.30 (VDD3_1), C68.2, C69.1
unnamed: A2.11 (LITE_PAD), R28.2, TP13.1 (1_1)
unnamed: A2.7 (RI), R38.1
unnamed: A2.10 (ROSC_SEL), TP11.1 (1_1)
unnamed: A2.3 (VDD1_0), C72.2, C73.1
unnamed: A2.28 (VDD1_1), C78.2, C79.1
unnamed: A2.2 (VDD2_0), C73.2, C74.1
unnamed: A2.29 (VDD2_1), C77.2, C78.1
unnamed: A2.1 (VDD3_0), C74.2, C75.1
unnamed: A2.30 (VDD3_1), C76.2, C77.1
unnamed: R23.2, U2.9 (OE)

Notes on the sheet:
0.8V LDO
1.2V LDO
Direction Control HIGH= A -> B LOW = A <- B

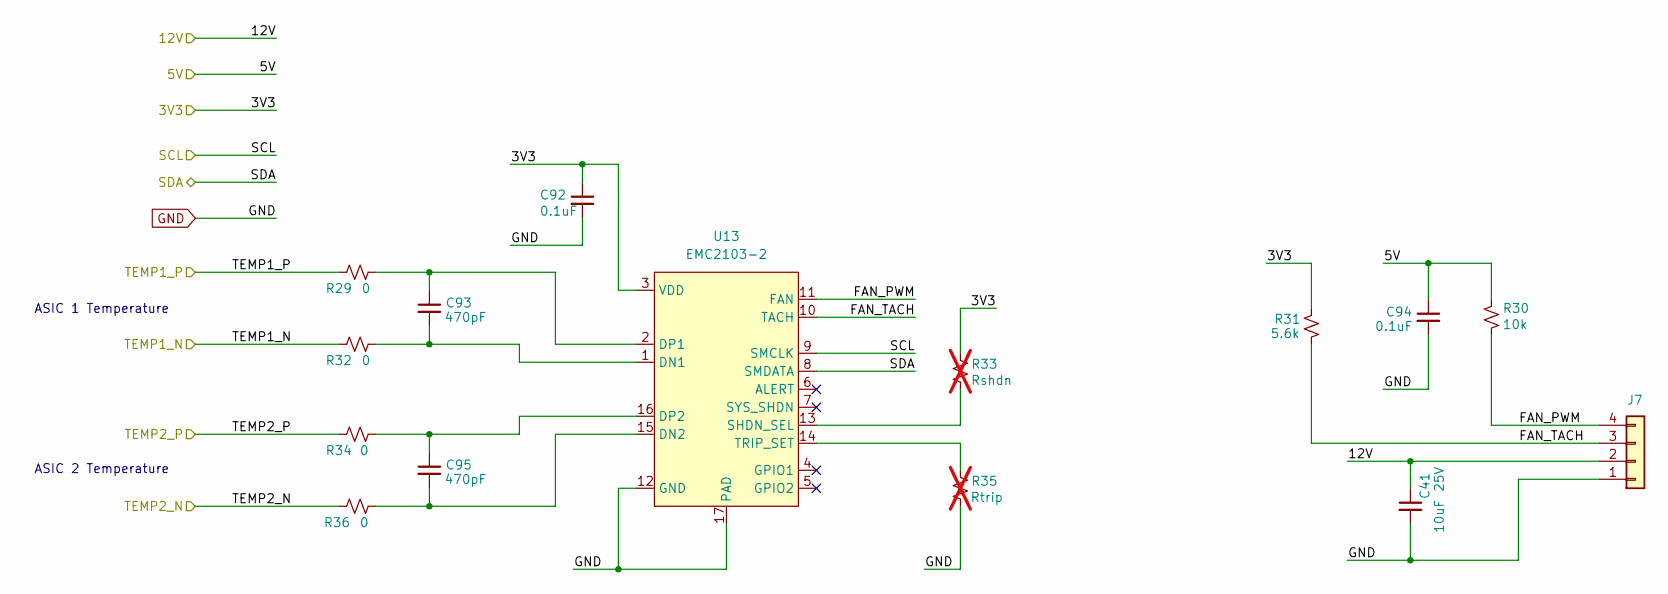
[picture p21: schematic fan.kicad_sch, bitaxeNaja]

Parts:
C41: 10uF; C_0603_1608Metric; Voltage 25V; PARTNO GRM188R61E106KA73D
C92, C94: 0.1uF; C_0402_1005Metric; PARTNO KGM05AR71C104KH
C93, C95: 470pF; C_0402_1005Metric; PARTNO GRM1555C1H471JA01D
J7: Conn_01x04; 470531000; PARTNO 0470531000
R29, R32, R34, R36: 0; R_0402_1005Metric; PARTNO RC0402JR-070RL
R30: 10k; R_0402_1005Metric; PARTNO RC0402JR-0710KL
R31: 5.6k; R_0402_1005Metric; PARTNO RC0402FR-075K6L
R33: Rshdn; R_0402_1005Metric; not fitted
R35: Rtrip; R_0402_1005Metric; not fitted
U13: EMC2103-2; QFN-16-1EP_4x4mm_P0.65mm_EP2.1x2.1mm; PARTNO EMC2103-4-AP-TR

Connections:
/3V3: C92.1, R31.2, R33.2, U13.3 (VDD); also elsewhere on the board
/5V: C94.1, R30.2; also elsewhere on the board
/12V: C41.1, J7.2; also elsewhere on the board
/ASIC/TEMP1_N: R32.2; also elsewhere on the board
/ASIC/TEMP1_P: R29.2; also elsewhere on the board
/ASIC/TEMP2_N: R36.2; also elsewhere on the board
/ASIC/TEMP2_P: R34.2; also elsewhere on the board
/ESP32/SCL: U13.9 (SMCLK); also elsewhere on the board
/ESP32/SDA: U13.8 (SMDATA); also elsewhere on the board
/fan/FAN_PWM: J7.4, R30.1, U13.11 (FAN)
/fan/FAN_TACH: J7.3, R31.1, U13.10 (TACH)
GND: C41.2, C92.2, C94.2, J7.1, R35.1, U13.12 (GND), U13.17 (PAD); also elsewhere on the board
unnamed: C93.2, R32.1, U13.1 (DN1)
unnamed: C95.2, R36.1, U13.15 (DN2)
unnamed: C93.1, R29.1, U13.2 (DP1)
unnamed: C95.1, R34.1, U13.16 (DP2)
unnamed: R33.1, U13.13 (SHDN_SEL)
unnamed: R35.2, U13.14 (TRIP_SET)

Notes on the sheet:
ASIC 2 Temperature
ASIC 1 Temperature

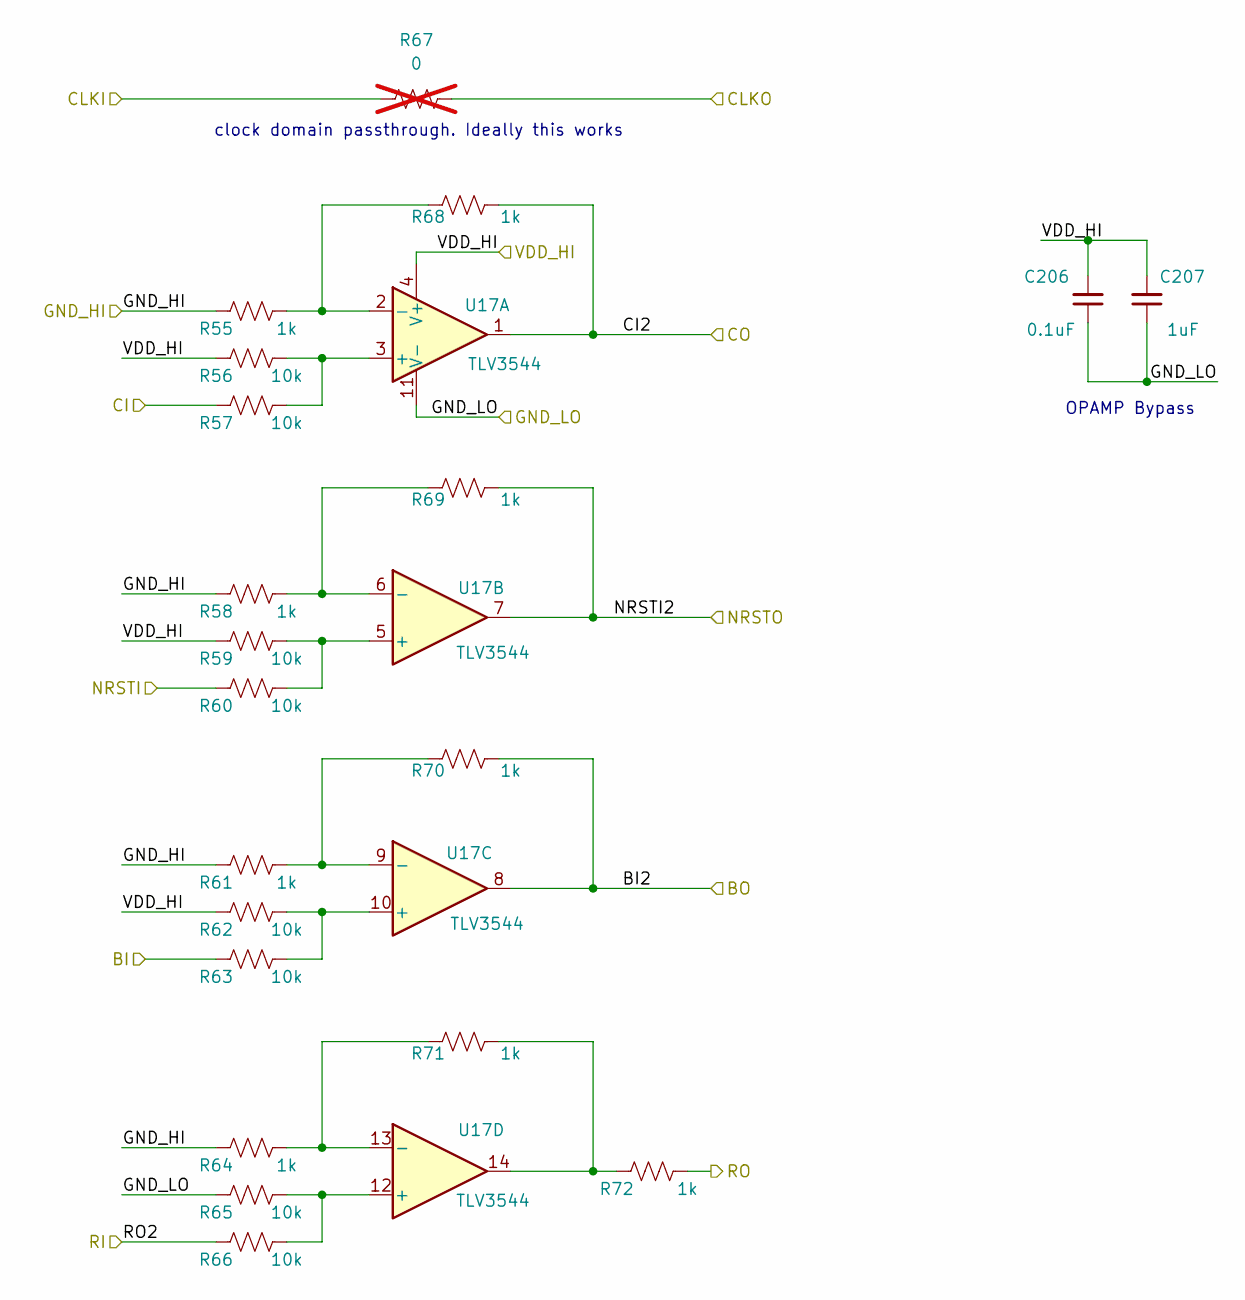
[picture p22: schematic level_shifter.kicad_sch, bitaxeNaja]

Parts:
C206: 0.1uF; C_0402_1005Metric; PARTNO KGM05AR71C104KH
C207: 1uF; C_0402_1005Metric; PARTNO EMK105BJ105MV-F
R55, R58, R61, R64, R68, R69, R70, R71, R72: 1k; R_0402_1005Metric; PARTNO RC0402FR-071KL
R56, R57, R59, R60, R62, R63, R65, R66: 10k; R_0402_1005Metric; PARTNO RC0402JR-0710KL
R67: 0; R_0402_1005Metric; PARTNO RC0402JR-070RL; not fitted
U17: TLV3544; TSSOP-14_4.4x5mm_P0.65mm; PARTNO TLV3544IPWR

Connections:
/ASIC/GND_1: R55.2, R58.2, R61.2, R64.2; also elsewhere on the board
/ASIC/Level Shifter/BI: R63.1; also elsewhere on the board
/ASIC/Level Shifter/BI2: R70.1, U17.8; also elsewhere on the board
/ASIC/Level Shifter/CI: R57.1; also elsewhere on the board
/ASIC/Level Shifter/CI2: R68.1, U17.1; also elsewhere on the board
/ASIC/Level Shifter/CLKI: R67.1; also elsewhere on the board
/ASIC/Level Shifter/CLKO: R67.2; also elsewhere on the board
/ASIC/Level Shifter/NRSTI: R60.1; also elsewhere on the board
/ASIC/Level Shifter/NRSTI2: R69.1, U17.7; also elsewhere on the board
/ASIC/Level Shifter/RO: R72.1; also elsewhere on the board
/ASIC/Level Shifter/RO2: R66.1; also elsewhere on the board
GND: C206.1, C207.1, R65.1, U17.11 (V-); also elsewhere on the board
unnamed: R71.1, R72.2, U17.14
unnamed: R56.1, R57.2, U17.3 (+)
unnamed: R55.1, R68.2, U17.2 (-)
unnamed: R59.2, R60.2, U17.5 (+)
unnamed: R58.1, R69.2, U17.6 (-)
unnamed: R62.2, R63.2, U17.10 (+)
unnamed: R61.1, R70.2, U17.9 (-)
unnamed: R65.2, R66.2, U17.12 (+)
unnamed: R64.1, R71.2, U17.13 (-)

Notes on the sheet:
OPAMP Bypass
clock domain passthrough. Ideally this works

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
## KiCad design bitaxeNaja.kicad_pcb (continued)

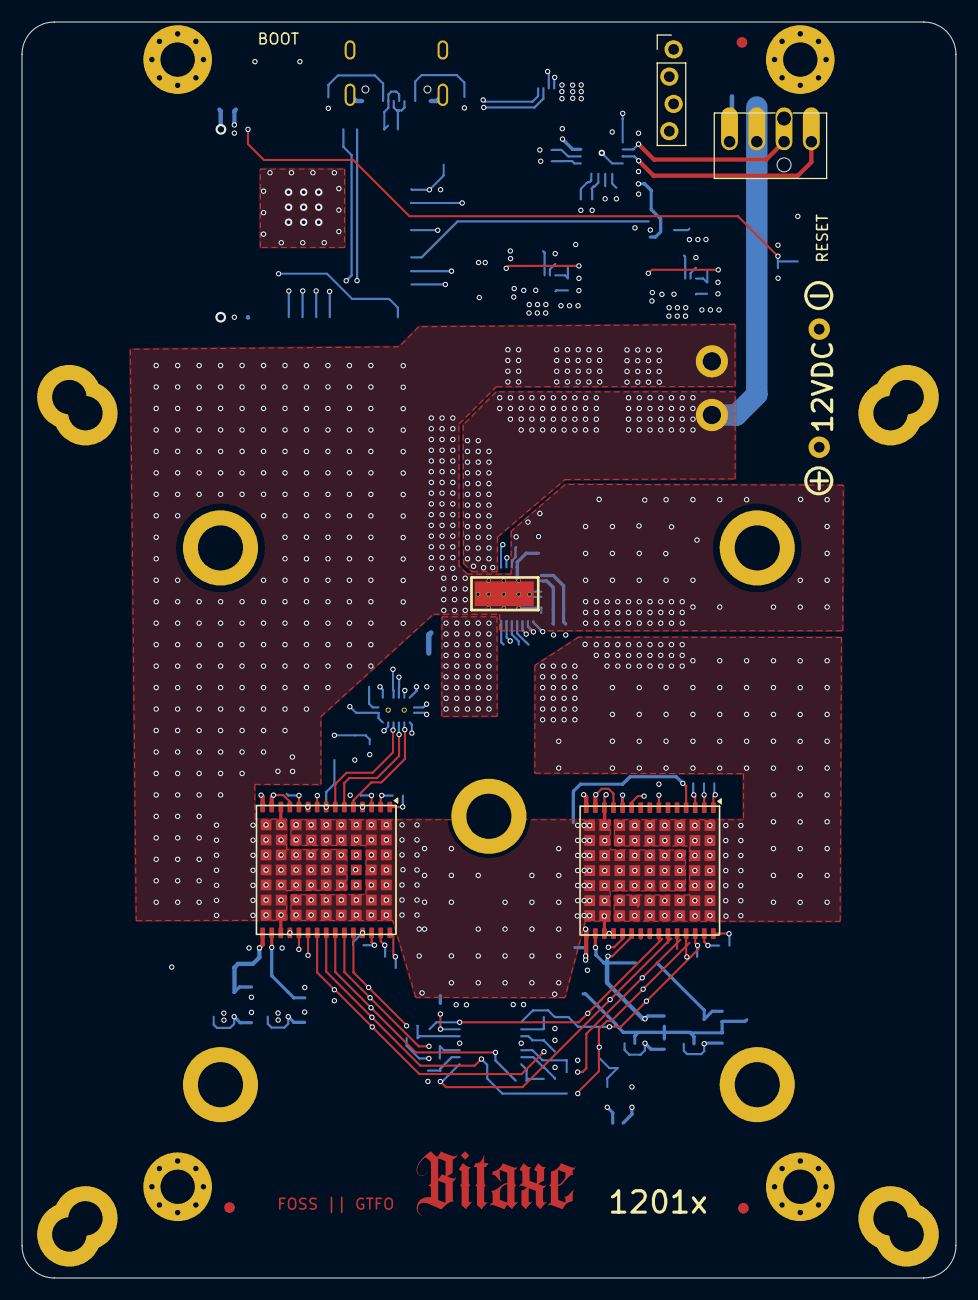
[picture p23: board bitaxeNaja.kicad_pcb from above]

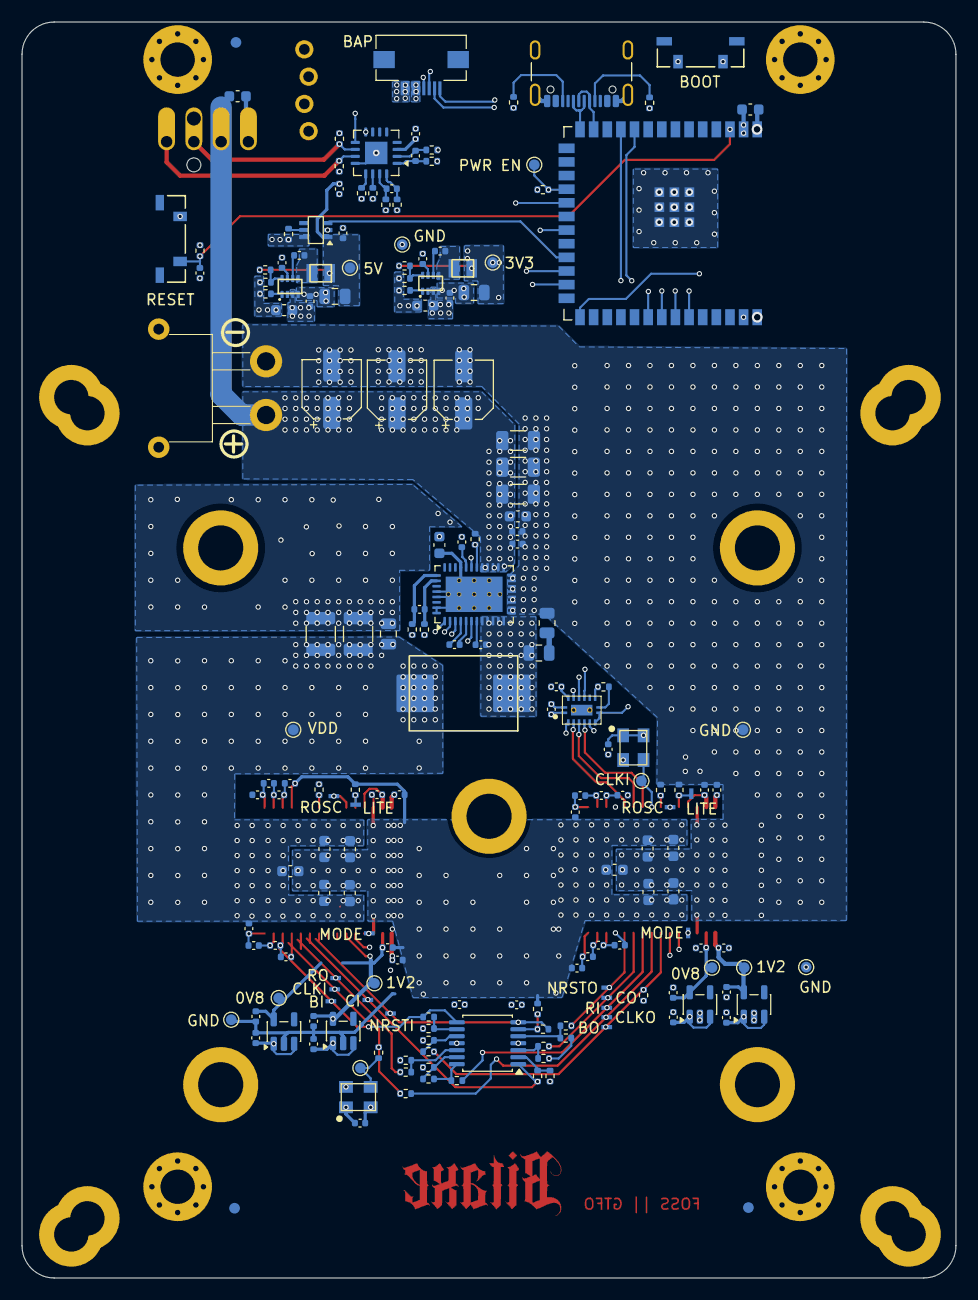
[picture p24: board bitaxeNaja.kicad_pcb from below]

Board: 6 copper layers, 87.0 x 117.0 mm, 198 parts (184 on the bottom side), 106 nets.

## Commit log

2025-07-17 initial import
    [141_TL3330AFxxxQG.stp, 21-0164B_L622-1_MXM.step, 2R5TPE220MAFB.step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]
2025-07-18 added BM1340 footprint
2025-07-18 updated power pads. added BM1370 pinout for BM1340 (??)
2025-07-19 lots of routing
    [ASIC.kicad_sch, BM1340.step, ESP32.kicad_sch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]
2025-08-01 placed and routed and DRC'd. updated TPS546 for 1.0V output.
    [ASIC.kicad_sch, ESP32-S3-WROOM-1-N8R2--3DModel-STEP-56544.STEP, ESP32.kicad_sch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]
2025-08-01 added checked gerbers and BOM
    [Power.kicad_sch, bitaxeNaja.kicad_pcb]
2025-08-04 added webench design
    [Power.kicad_sch]
2026-04-15 update to KiCad 10
    [ASIC.kicad_sch, ESP32.kicad_sch, Power.kicad_sch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]
2026-06-18 switched to single phase TPS546D24 and put the ASICs in series.
    [ASIC.kicad_sch, ESP32.kicad_sch, Power.kicad_sch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]
2026-06-24 rough parts placement.
    [ASIC.kicad_sch, Fan 60x60x25mm.stp, GDIM107050-R15S1MTF-0R37.step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]
2026-06-25 finished placing parts. lots of routing.
    [ASIC.kicad_sch, ESP32.kicad_sch, bitaxeNaja.kicad_pcb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]
2026-06-25 add missing 3d models
    [DCK0006A.stp, IND-SMD_L11.0-W7.2-H7.5.step, IND-SMD_L2.0-W1.6-H1.1.step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]
2026-06-25 finished routing
    [ASIC.kicad_sch, Power.kicad_sch, bitaxeNaja.kicad_pcb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]
2026-06-25 DRC pass
    [bitaxeNaja.kicad_pcb]
2026-06-26 make the PCB bigger for 70mm heatsink mounting holes
    [bitaxeNaja.kicad_pcb, bitaxeNaja.kicad_sch]

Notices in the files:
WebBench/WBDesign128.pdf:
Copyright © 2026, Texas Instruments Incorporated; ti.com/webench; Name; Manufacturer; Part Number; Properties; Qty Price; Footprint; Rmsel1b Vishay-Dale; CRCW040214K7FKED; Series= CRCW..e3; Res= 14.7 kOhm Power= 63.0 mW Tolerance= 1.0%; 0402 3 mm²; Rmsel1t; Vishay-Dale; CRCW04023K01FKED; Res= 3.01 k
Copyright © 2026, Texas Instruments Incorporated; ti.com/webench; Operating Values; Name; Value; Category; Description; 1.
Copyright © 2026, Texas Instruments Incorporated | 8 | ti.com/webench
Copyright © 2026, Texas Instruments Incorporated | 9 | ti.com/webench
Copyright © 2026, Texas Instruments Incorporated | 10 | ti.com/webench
